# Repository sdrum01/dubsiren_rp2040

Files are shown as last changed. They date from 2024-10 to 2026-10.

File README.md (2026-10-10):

# DUB-IY Dub Siren with RP2040 CPU

DUBSIREN_rp2040 is a project designed to emulate a analog frequency generator for dub and reggae music. The result is the "**DUB-IY**" dub siren. 

Dub sirens are simple synthesizers without VCA (Voltage Controlled Amplifier) or VCF (Voltage Controlled Filter), but usually with a VCO (Voltage Controlled Oscillator) modulated by an LFO (Low Frequency Generator).

Such sirens are typically built with analog circuits. The challenge, however, was to optimize the parameter storage of digital solutions, simplify the electronics and to make it hackable.

**DUB-IY** is based on a Raspberry Pi Pico with an RP2040 CPU. It is fast enough to emulate VCOs and LFOs and offers sufficient options for internal data storage.

The Dub siren creates an square wave signal with an adjustable duty cycle. The sound can be modulated by two LFOs and an envelope generator to modulate the timing parameter. 

Finally, the signal is perfected with an integrated echo effect. 

The following values can be adjusted using potentiometers and switches:

* LFO1 waveform
(square, triple square, triangle, sawtooth, pulse)
* LFO2 waveform (square, triangle, sawtooth)
* Oscillator base frequency
* LFO1 and LFO2 frequency
* LFO1 and LFO2 contribution (negative and positive)
* Timing envelope contribution
* Oscillator waveform duty cycle
* LFO start retriggering
* Delay time (echo)
* Feedback (echo)
* Overall volume

The combination of LFOs 1 and 2 already produces many experimental siren sounds,
but the timing envelope adds significantly more dynamics to the sound.

>[!NOTE]
   >
   >This is a non-profit project with no goal of making big money.
   >It's purely for fun, and we assume no liability!
   
## Waiting List

To reserve one device or PCB pls write me an email: dub-iy@sdrum.elementfx.com

## Documentation

Have a look into the short introduction on YouTube:

- [DUB-IY Introduction](https://youtu.be/Yc06HZqR8gg?si=ktLNwQYJj4XRiWYL) 

There is also a manual explaining the various functions:

- [English Manual](docs/en/index.md)
- [Kurzanleitung Deutsch](docs/de/index.md)

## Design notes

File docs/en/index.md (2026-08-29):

8# DUB-IY short manual 

14.07.2025
<p align="right"><a href="../de">[German version]</a></p>

The Dub Siren DUB-IY is an electronic sound generator that can be used in Dub and Reggae music. It produces modulated, siren-like sounds or effects that can be layered rhythmically or improvised over a track.

## Overview



**Fire Button 1-4 (F1 - F4):** 

Fire a sound. Fire Buttons 1-4 play the saved or edited sounds. Releasing the buttons stops the sound unless one of the adjacent buttons is pressed.

**Fire button 1-4 + Fire Button next to it**:

Hold sound until Fire Button is pressed again.

**Shift (S3) + Fire Button 1-4:**

Select memory bank: Fire Buttons 1-4 load the sounds of the selected bank from memory. A bank consists of 4 buttons. This allows up to 16 sounds to be stored:

- Bank1: 1 to 4
- Bank2: 5 to 8
- Bank3: 9 to 12
- Bank4: 13 to 16

**Save (S4) + Fire Button 1-4:** 

Save sound: any newly edited sound can be easily saved to a Fire Button using this key combination.
Any previously saved sound in the same location will be overwritten.

**Basic state**

If no key is pressed, the last used Fire Button will flash briefly. This shows which sound is currently selected and being edited. This is very helpful before saving to avoid accidentally overwriting a sound.

## Sound Edit 

The sound parameters can be influenced by the following potentiometers (knobs):

**Tune (P1):** Pitch of tone

**Speed (P2):** Speed of the selected LFO

**Mod (P3):** Modulation strength of the selected LFO

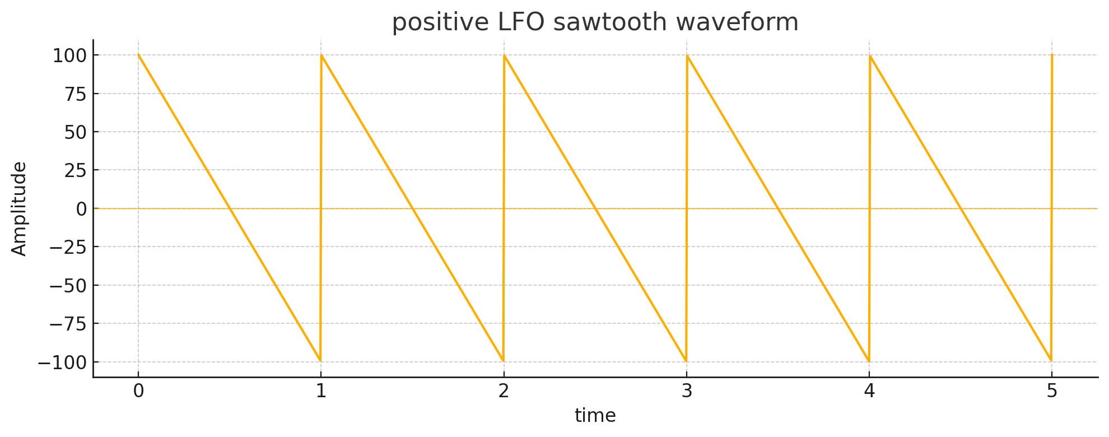
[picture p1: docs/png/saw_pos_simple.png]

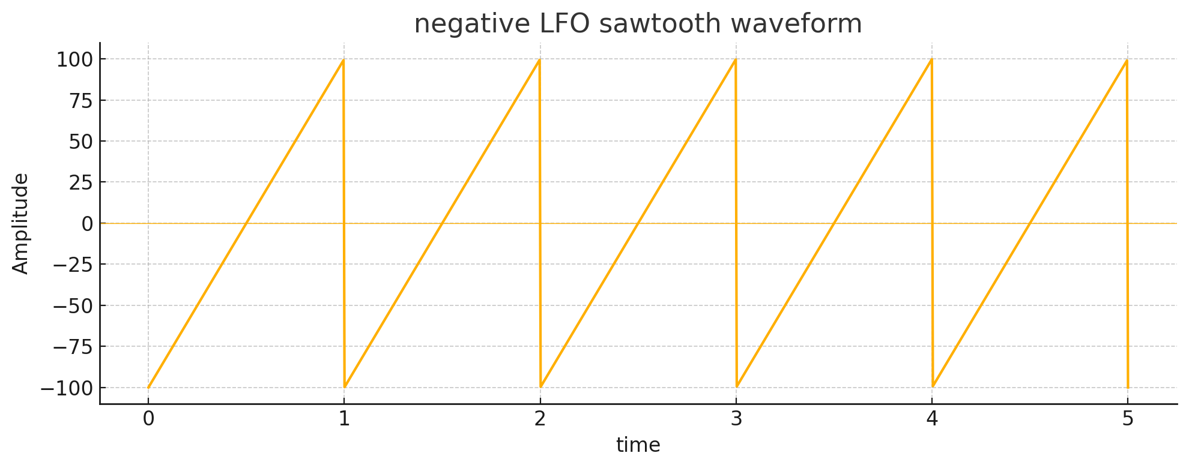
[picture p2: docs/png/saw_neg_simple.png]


_Example of the positive and negative modulation strength of the LFO on a sawtooth wave_

## Sound Edit "Shift Mode" (Shift LED on -> S3)

**Shift Button (S3)**: Switching from normal Sound Edit mode to Sound Edit "Shift Mode."

In "Shift Mode," the potentiometers (knobs) P1, P2, and P3 acquire new functions:

**Tune (P1):** affects the duty cycle (pulse width) of the tone. By default, the pulse width of the tone is 50%, which can be made "thinner."

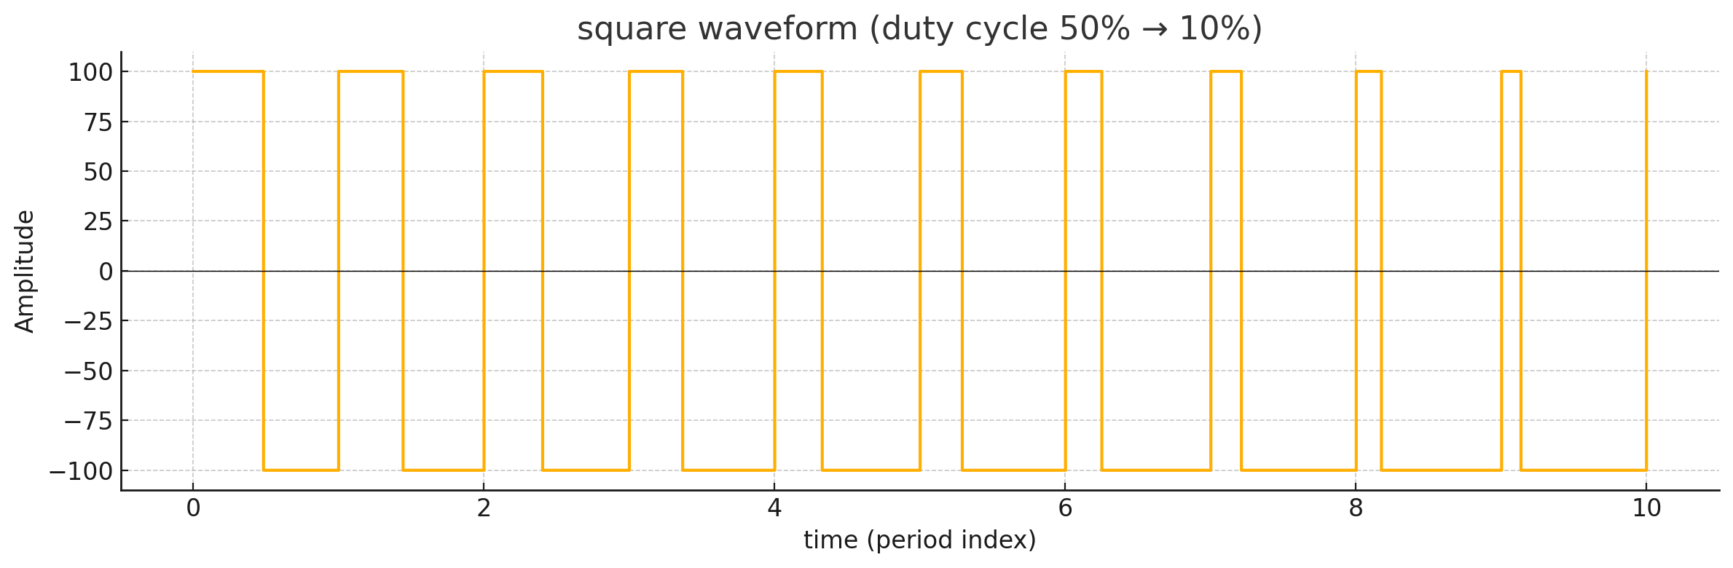
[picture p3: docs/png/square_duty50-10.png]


_Square wave of the tone with pulse width 50% to 10%_

**Speed (P2):** Influences the speed of the LFO with an envelope generator.
This allows the LFO's speed to be changed dynamically.

**Mod (P3):** Influences the modulation strength of the envelope generator:
- Negative value: slow -> fast
- Positive value: fast -> slow

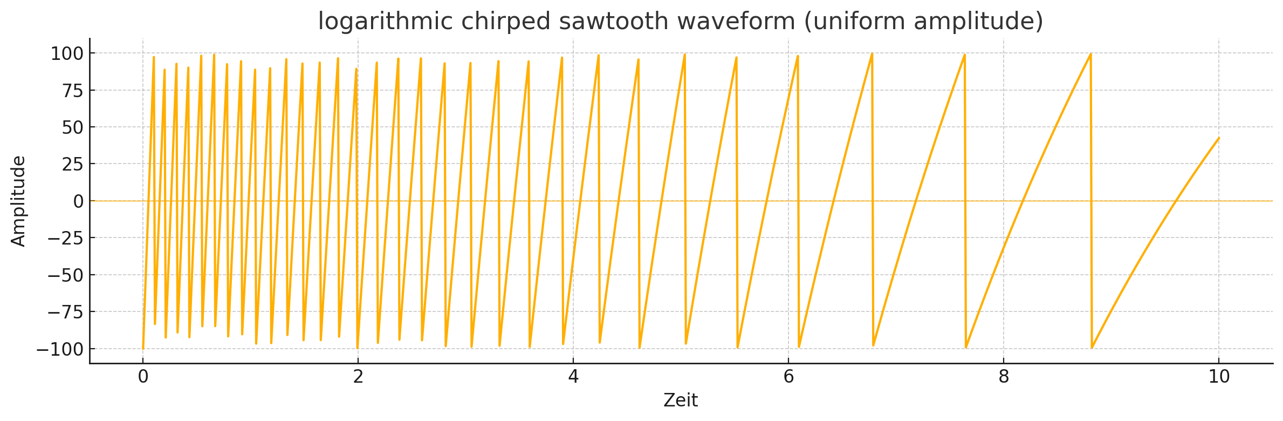
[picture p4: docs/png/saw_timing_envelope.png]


_Example of influencing a sawtooth LFO by the timing envelope generator_.

> [!TIP]
> The timing generator (P2) influences the speed of the active LFO (see [Function Buttons](#function-buttons)).

## Function Buttons

The DUB-YI features two LFOs (low-frequency oscillators) that generate the waveforms used to modulate the sound.

**Wave Button (S1):** 

Selecting the waveform for the selected LFO:

For each LFO, 3 waveforms are selectable
- Rectangle 
- Triangle 
- Sawtooth 
  
The strength and type of the waveform are influenced positively or negatively by the modulation strength (P3), depending on the selected value. At the center position of P3 (0), the respective LFO no longer has any influence.
 
The P3 control has a special feature for LFO1 with the selected waveform "square":
- Positive value: 2 pitches 
- Negative value Wert: 3 pitches 
- Minimal value: interrupted sound 

**LFO Button (S2):** 

Select LFO1 or LFO2.

Each LFO has an independent, storable set of parameters that can be adjusted via P1, P2, and P3.

Both LFOs influence (modulate) each other.

## Examples of Modulation

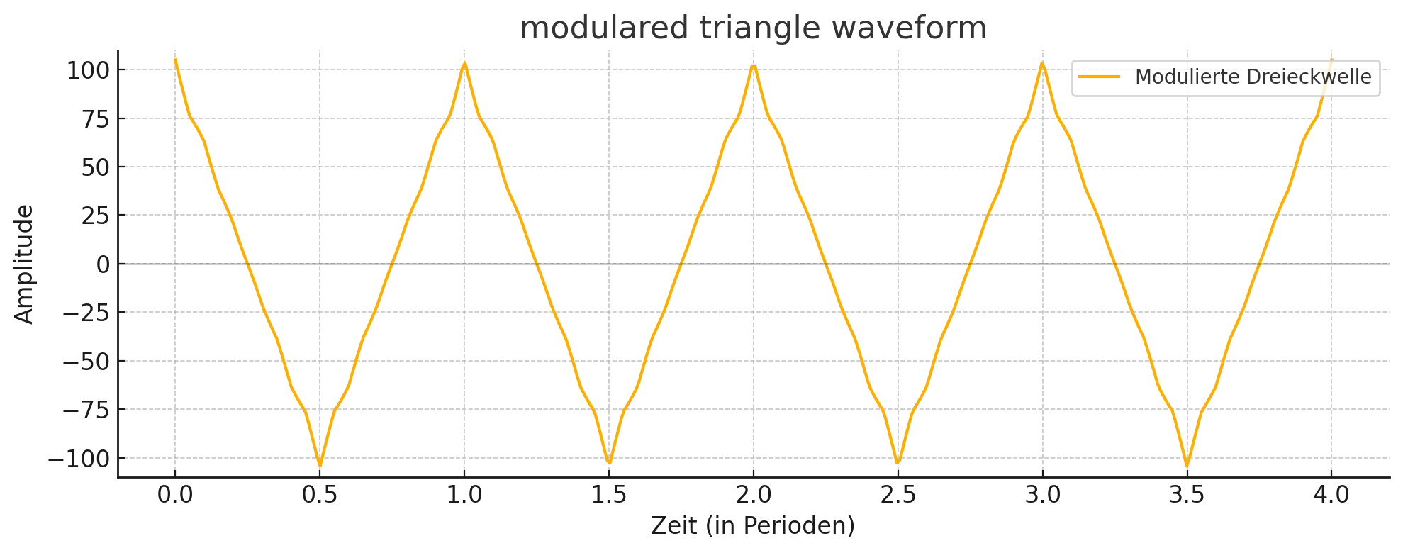
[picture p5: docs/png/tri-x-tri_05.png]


_Modulating a triangle wave from LFO1 with a faster triangle wave from LFO2 at 5%. This creates a slight "vibrato effect"_.

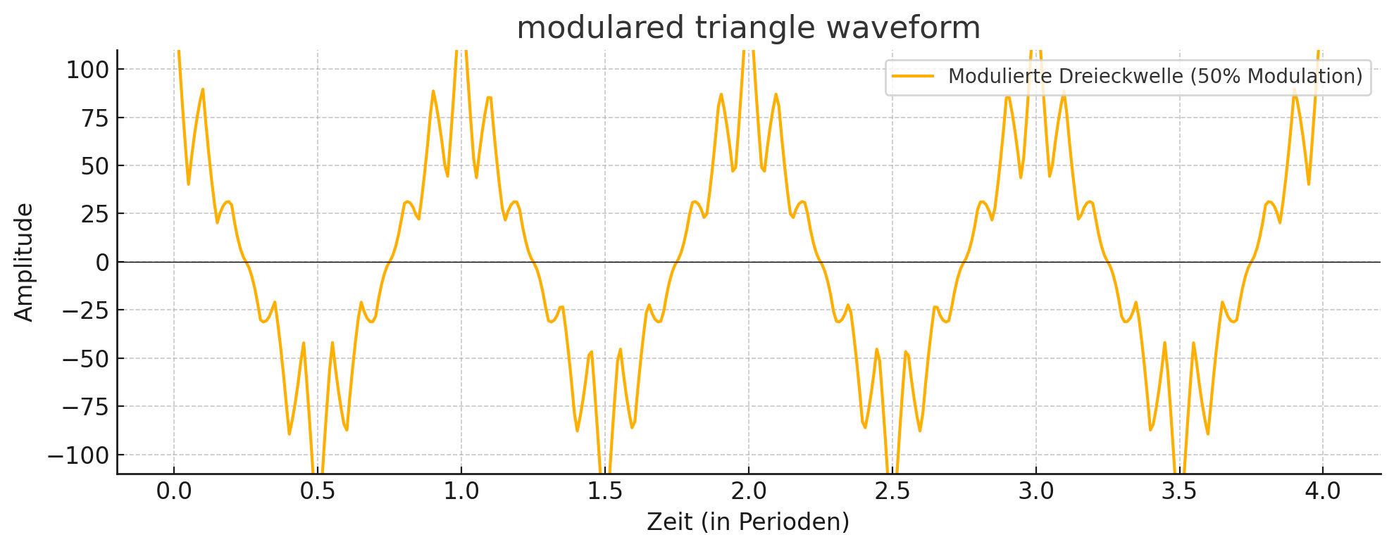
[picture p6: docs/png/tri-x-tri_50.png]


_Modulation of a triangle wave from LFO1 with the triangle wave from LFO2, but with +50% modulation strength_.

## Special Functions / Flags

> [!CAUTION]
> Experimental functions

**LFO Button (S2) pressed + Fire Button 1-4:** 

Various special functions can be switched on using 4 flags.

**Fire1 = Flag1**: LFO2 always starts when a new sound is fired.

**Fire2 = Flag2**: One Shot: after LFO1 has played a full period, the sound stops.

**Fire3 = Flag3**: Modulation multiplier x 2

**Fire4 = Flag4**: Unused

Flag 1 is set by default for new sounds so that LFO1 and LFO2 always start together when the Fire Buttons are pressed. If Flag 1 is turned off, LFO2 continues to run and starts randomly somewhere after the Fire Button is pressed.

## Panic Function (Reset LFO2 and Timing Envelope)

If the sound has become too complex and you just want to hear the basic sound again, you can simply turn off LFO2 and the Timing Envelope by pressing buttons S3 and S4 simultaneously.

## Echo / Delay Effect / Master Volume

**Delay (E1)**: Delay time of the echo, from short to long

**Feedback (E2)**: Strength with which the echo is mixed with the output signal and strength of the feedback of the input signal. At maximum value, the feedback is infinitely long.

**Vol (E3)**: Master Output Volume

> [!Important]
> Echo and master volume (parameters E1 to E3) cannot be saved!

---

> [!Note]
> We reserve the right to improve or adapt the functionality as needed.

Contact dub-iy (at) sdrum.elementfx.com

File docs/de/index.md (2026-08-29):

# DUB-IY Kurzanleitung 

14.07.2025
<p align="right"><a href="../en">[Englische Version]</a></p>

Die Dubsirene DUB-IY ist ein elektronisches Soundgenerator, das in der Dub- und Reggae-Musik eingesetzt werden kann. Sie erzeugt modulierte, sirenenartige Töne oder Effekte, die rhythmisch oder improvisiert über einen Track gelegt werden kann.

## Übersicht



**Firebutton 1-4 (F1 - F4):** 

Sound abfeuern. Mit den Firebuttons 1-4 werden die abgespeicherten oder editierten Sounds abgespielt. Beim Loslassen der Buttons stoppt der Sound, es sei denn, eine der Nachbartasten wurde gedrückt.

**Firebutton 1-4 + benachbarter Firebutton**:

Sound halten bis Firebutton erneut gedrückt wurde.

**Shift (S3) + Firebutton 1-4:**

Speicherbank wählen: Mit den Firebuttons 1-4 werden die Sounds der gewählten Bank aus dem Speicher geladen. Eine Bank besteht aus jeweils vier Buttons. Damit können bis zu 16 Sounds gespeichert werden:

- Bank1: 1 bis 4
- Bank2: 5 bis 8
- Bank3: 9 bis 12
- Bank4: 13 bis 16

**Save (S4) + Firebutton 1-4:** 

Sound abspeichern: Jeder neue editierte Sound kann einfach auf einen Firebutton mit dieser Tastenkombination gespeichert werden. 
Ein eventuell zuvor gespeicherter Sound auf dem selben Speicherplatz wird dabei überschrieben.

**Grundzustand**

Wenn keine Taste gedrückt wurde, blinkt der zuletzt benutzte Firebutton immer wieder kurz. Dadurch ist ersichtlich, welcher Sound gerade gewählt und editiert wird. Dies ist sehr hilfreich vor dem Speichern, um nicht versehentlich einen Sound zu überschreiben.

## Sound Edit 

Die Parameter der Sounds können durch folgende Potentiometer (Drehregler)
beeinflusst werden:

**Tune (P1):** Tonhöhe (Pitch) des Tons

**Speed (P2):** Geschwindigkeit des gewählten LFO

**Mod (P3):** Modulationsstärke des gewählten LFO




_Beispiel der positiven und negativen Modulationsstärke des LFO bei einer Sägezahnwelle_

## Sound Edit "Shift Mode" (Shift LED an -> S3)

**Shift-Button (S3)**: Umschalten vom normalen Sound-Edit mode in den Sound Edit "Shift Mode".

Im "Shift Mode" bekommen die Potentiometer (Drehregler) P1, P2, P3 neue Funktionen:

**Tune (P1):** beeinflusst das Duty Cycle (Pulsbreite) des Tons. Standardmäßig ist die Pulsbreite des Tons 50%, und kann dadurch "dünner" gemacht werden.



_Rechtecksignal des Tons mit Pulsbreite 50% bis 10%_

**Speed (P2):** beeinflusst die Geschwindigkeit des LFO mit einem Envelop-Generator (Hüllkurven-Generator)
Dadurch kann der LFO dynamisch in seiner Geschwindigkeit geändert werden 

**Mod (P3):** beeinflusst die Modulationsstärke des Envelop-Generator:
- negativer Wert: langsam -> schnell 
- positiver Wert: schnell -> langsam



_Beispiel einer Beeinflussung eines Sägezahhn-LFO durch den Timing-Envelope-Generator_.

> [!TIP]
> Der Timing-Generator (P2) beeinflusst die Geschwindigkeit des aktiven LFO (siehe [Funktionsbuttons](#funktionsbuttons)).

## Funktionsbuttons

Das DUB-YI verfügt über zwei LFO (Low-Frequency Oscillator), welche
die Wellenformen erzeugen, mit dem der Ton moduliert wird.

**Wave-Button (S1):** 

Selektieren der Wellenform für den gewählten LFO:

Bei jedem LFO sind grundsätzlich 3 Wellenformen selektierbar
- Rechteck 
- Dreieck 
- Sägezahn 
  
Die Stärke und zum Teil die Art der Wellenform wird durch die Modulationsstärke (P3) positiv / negativ in Abhängigkeit des gewählten Wertes beeinflusst. Bei der Mittelstellung von P3 (0) hat der jeweilige LFO keinen Einfluss mehr.
 
Beim LFO1 hat der Regler P3 mit gewählter Wellenform "Rechteck" eine Besonderheit:
- positiver Wert: 2 Töne 
- negativer Wert: 3 Töne 
- Minimaler Wert: Unterbrochener Ton 

**LFO-Button (S2):** 

Selektieren von LFO1 oder LFO2.

Jeder LFO hat einen unabhängigen, abspeicherbaren Parametersatz, der über P1, P2, P3 eingestellt werden kann. 
Beide LFO beeinflussen (modulieren) sich gegenseitig.

## Beispiele der Modulation



_Modulation einer Dreieckwelle von LFO1 mit einer schnelleren Dreieckwelle LFO2 mit 5%_. _Es entsteht ein leichter "Vibrato-Effekt"_.



_Modulation einer Dreieckwelle von LFO1 mit der Dreieckwelle LFO2, aber mit +50% Modulationsstärke_.

## Spezialfunktionen / Flags

> [!CAUTION]
> Experimentelle Funktion

**LFO-Button (S2) gedrückt + Firebutton 1-4:** 

Über 4 Flags verschiedene Sonderfunktionen eingeschaltet werden.

**Fire1 = Flag1**: LFO2 startet immer bei neu beim abfeuern von Sounds.

**Fire2 = Flag2**: One Shot: nach dem LFO1 eine vollständige Periode gespielt hat, wird der Sound gestoppt

**Fire3 = Flag3**: Multiplikator der Modulation x 2

**Fire4 = Flag4**: Unbenutzt

Flag 1 ist standardmäßig bei neuen Sounds gesetzt, damit LFO1 und LFO2 beim Drücken der Firebuttons immer zusammen gestartet werden. Wenn Flag 1 ausgeschaltet wird, läuft der LFO2 weiter und startet nach dem drücken des Firebutton irgendwo zufällig.

## Panik-Funktion (Reset LFO2 und Timing-Envelope)

Sollte der Sound zu komplex geworden sein, und man möchte nur wieder den Grundsound hören, kann man den LFO2 und den Timing-Envelope einfach ausschalten, indem man die Taster S3 + S4 gleichzeitig drückt.

## Echo / Delayeffekt / Mastervolume

**Delay (E1)**: Verzögerungszeit des Echo, von kurz nach lang

**Feedback (E2)**: Stärke, mit der das Echo dem Ausgangssignal zugemischt wird und Stärke der Rückkopplung (Feedback) des Eingangssignals. Bei maximalem Wert ist das Feedback unendlich lang.

**Vol (E3)**: Ausgangslautstärke Master

> [!Important]
> Echo und Mastervolume (Parameter E1 bis E3) sind nicht abspeicherbar! 

---

> [!Note]
> Wir behalten uns vor, die Funktionalität bei Bedarf zu verbessern oder anzupassen. 

Kontakt
dub-iy (at) sdrum.elementfx.com

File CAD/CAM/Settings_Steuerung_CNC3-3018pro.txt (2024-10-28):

Version=11244
Setting type=CNC controller settings

;----------------------------------------------------------------------------------------------------------------------------------------------------
;Vor Änderungen an dieser Datei muss Estlcam unbedingt geschlossen werden - sonst gehen die Änderungen verloren!
;Die "Steuerungselektronik" Liste der Grundeinstellungen setzt alles auf Standardwerte zurück - klicke Sie nach manuellen Änderungen nicht mehr an!
;----------------------------------------------------------------------------------------------------------------------------------------------------

Enabled=yes
Hardware=G_Safe
Firmware=G_Safe
Last Upload=11244
Port=COM19

;Axis configuration
Steps rev X=3200
Steps rev Y=3200
Steps rev Z=3200
Distance rev X=4
Distance rev Y=4
Distance rev Z=4
Fmax X=20
Fmax Y=20
Fmax Z=20
Inertia X=85
Inertia Y=85
Inertia Z=85
Inverted X=no
Inverted Y=yes
Inverted Z=no
Current X=0,5
Current Y=0,5
Current Z=0,5

Acceleration distance=2
Min feedrate=1
Fast Diagonal=no
Invert enable output=no
Invert step signal=no
Switch enable output=no

Override oversampling=-1
Override pulse=-2147483648
Pulse pause=0
Manual programming reset=no

Position X=41238
Position Y=0
Position Z=800000
Home offset X=0
Home offset Y=0
Home offset Z=0
Feedrate=10
RPM=24000
Last CNC file=G:\Produktion\AV\Automation\SSA\RnD\Software\tools\CAM\estlcam\test\Zeichnung.nc
Last CNC line=0
Last CNC rotation=0
Balance message=yes

;Spindle configuration
RPM min=8000
RPM max=24000
RPM delay=1
PWM min=0
PWM max=100
PWM Frequency=0
Spindle output inverted=no

;Inputs
Input 1 name=Eingang 1
Input 1 function=0
Input 1 inverted=no
Input 1 pull-up=yes

Input 2 name=Eingang 2
Input 2 function=0
Input 2 inverted=no
Input 2 pull-up=yes

Input 3 name=Eingang 3
Input 3 function=0
Input 3 inverted=no
Input 3 pull-up=yes

Input 4 name=Eingang 4
Input 4 function=0
Input 4 inverted=no
Input 4 pull-up=yes

Input 5 name=Eingang 5
Input 5 function=0
Input 5 inverted=no
Input 5 pull-up=yes

Input 6 name=Eingang 6
Input 6 function=0
Input 6 inverted=no
Input 6 pull-up=yes

Input 7 name=Eingang 7
Input 7 function=0
Input 7 inverted=no
Input 7 pull-up=yes

Input 8 name=Eingang 8
Input 8 function=0
Input 8 inverted=no
Input 8 pull-up=yes

Input 9 name=Eingang 9
Input 9 function=0
Input 9 inverted=no
Input 9 pull-up=yes

Input 10 name=Eingang 10
Input 10 function=0
Input 10 inverted=no
Input 10 pull-up=yes

Input 11 name=Eingang 11
Input 11 function=0
Input 11 inverted=no
Input 11 pull-up=yes

Input 12 name=Eingang 12
Input 12 function=0
Input 12 inverted=no
Input 12 pull-up=yes

Input 13 name=Eingang 13
Input 13 function=0
Input 13 inverted=no
Input 13 pull-up=yes

Input 14 name=Eingang 14
Input 14 function=0
Input 14 inverted=no
Input 14 pull-up=yes

Input 15 name=Eingang 15
Input 15 function=0
Input 15 inverted=no
Input 15 pull-up=yes

Input 16 name=Eingang 16
Input 16 function=0
Input 16 inverted=no
Input 16 pull-up=yes

;Outputs
Output 1 name=Ausgang 1
Output 1 picture=img_flood

Output 2 name=Ausgang 2
Output 2 picture=img_mist

Output 3 name=Ausgang 3
Output 3 picture=img_vac

Output 4 name=Ausgang 4
Output 4 picture=img_compressor

Output 5 name=Ausgang 5
Output 5 picture=img_light

Output 6 name=Ausgang 6
Output 6 picture=

Output 7 name=Ausgang 7
Output 7 picture=

Output 8 name=Ausgang 8
Output 8 picture=

;Homing
Auto home=no
Home switch location X=0
Home switch location Y=0
Home switch location Z=1
Homing speed=20
Homing probe speed=1
Homing switch precise=no
Homing back up distance=5
Check step losses=yes
Zero after homing=no
Travel limits enabled=no
Travel limit X=1000
Travel limit Y=1000
Travel limit Z=1000
Deceleration distance=25
Park after homing=no
Park after controller start=no
Park after CNC program end=no
Park after M00 M01=no
Parking position X=0
Parking position Y=0
Parking position Z=0
Homing Safety Msg=no

;Tool sensor
Tool sensor probe speed=0,10000000000000001
Tool sensor back up distance=1
Tool sensor fixed position=no
Tool sensor fixed position X=0
Tool sensor fixed position Y=0
Tool sensor fixed position Z=0
Tool sensor fixed Z=no
Tool sensor Z value=0

;Touch plate
Touch plate probe speed=5
Touch plate probe distance=20
Touch plate angle measurement distance=50
Touch plate margin X=5
Touch plate margin Y=5
Touch plate margin Z=5

;Keyboard
Keyboard enabled=yes
Key 0=104
Key 1=105
Key 2=102
Key 3=99
Key 4=98
Key 5=97
Key 6=100
Key 7=103
Key 8=33
Key 9=34
Key 10=38
Key 11=40
Key 12=39
Key 13=37
Key 14=113
Key 15=32
Key 16=50
Key 17=51
Key 18=52
Key 19=53
Key speed 0=2
Key speed 1=10
Key speed 2=25
Key speed 3=50
Key speed 4=100

;Gamepad
Gamepad enabled=no
Gamepad low speed=2
Gamepad high speed=100
Gamepad exponent=60
Gamepad sensitivity=2
Gamepad single axis=no
Gamepad beep=no

;External controls
Feed override knob enabled=no
Feed override knob min pos=13107
Feed override knob max pos=52429
Spindle override knob enabled=no
Spindle override knob min pos=13107
Spindle override knob max pos=52429
Jog wheel enabled=no
Jog wheel X inverted=no
Jog wheel Y inverted=no
Jog wheel Z inverted=no
Jog wheel coupled 1=yes
Jog wheel coupling factor 1=1:1
Jog wheel speed 1=10
Jog wheel coupled 2=yes
Jog wheel coupling factor 2=2:1
Jog wheel speed 2=50
Jog wheel coupled 3=yes
Jog wheel coupling factor 3=1:1
Jog wheel speed 3=100
Jog wheel coupled 4=no
Jog wheel coupling factor 4=1:1
Jog wheel speed 4=10
Jog wheel coupled 5=no
Jog wheel coupling factor 5=1:1
Jog wheel speed 5=50
Jog wheel coupled 6=no
Jog wheel coupling factor 6=1:1
Jog wheel speed 6=100
Jog wheel sensitivity=75
Joystick X enabled=no
Joystick Y enabled=no
Joystick Z enabled=no
Joystick X inverted=no
Joystick Y inverted=no
Joystick Z inverted=no
Joystick X center=50
Joystick Y center=50
Joystick Z center=50
Joystick X backlash=10
Joystick Y backlash=10
Joystick Z backlash=10
Joystick speed 1=100
Joystick speed 2=10
Joystick speed 3=20
Joystick speed 4=100
Joystick speed 5=100
Joystick speed 6=100
Joystick expo 1=60
Joystick expo 2=0
Joystick expo 3=0
Joystick expo 4=0
Joystick expo 5=0
Joystick expo 6=0
Joystick single axis 1=no
Joystick single axis 2=yes
Joystick single axis 3=yes
Joystick single axis 4=no
Joystick single axis 5=no
Joystick single axis 6=no
Joystick beep 1=yes
Joystick beep 2=yes
Joystick beep 3=yes
Joystick beep 4=no
Joystick beep 5=no
Joystick beep 6=no
Joystick sensitivity=70
Module=

Webcam application=
Webcam window margin left=0
Webcam window margin right=0
Webcam window margin top=0
Webcam window margin bottom=0
Webcam tool offset X=0
Webcam tool offset Y=0
Webcam tool offset Z=0
Webcam aligned to preview=no

Makro Name 1=
Makro 1=
Makro Name 2=
Makro 2=
Makro Name 3=
Makro 3=
Makro Name 4=
Makro 4=
Makro Name 5=
Makro 5=

;Misc
Back up distance=1
Surface scan speed=2
Touch mode=no

;Bootloader
Bootloader Baudrate=57600
Bootloader Reset_Time=20
Bootloader Wait_Time=500

Preset info=

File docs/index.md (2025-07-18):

# DUB-IY Kurzanleitung 

<p align="center"><a href="en/">[Englische Version]</a></p>
<p align="center"><a href="de/">[Deutsche Version]</a></p>



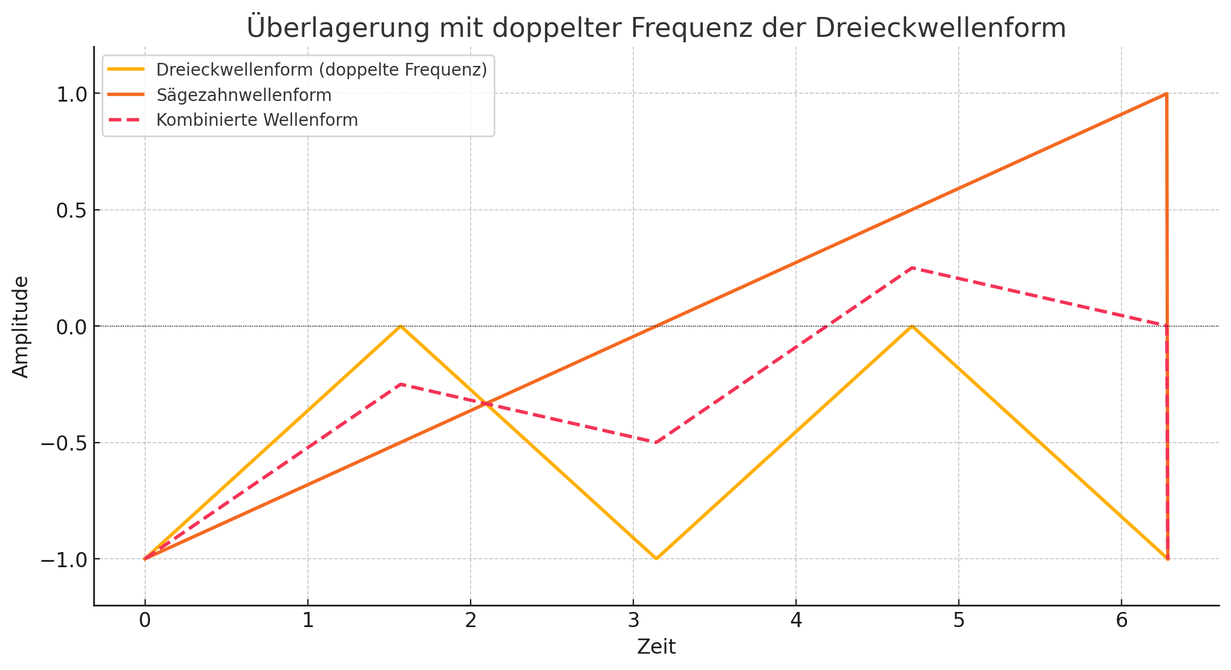
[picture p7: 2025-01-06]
docs/png/saw-x-tri_50.png

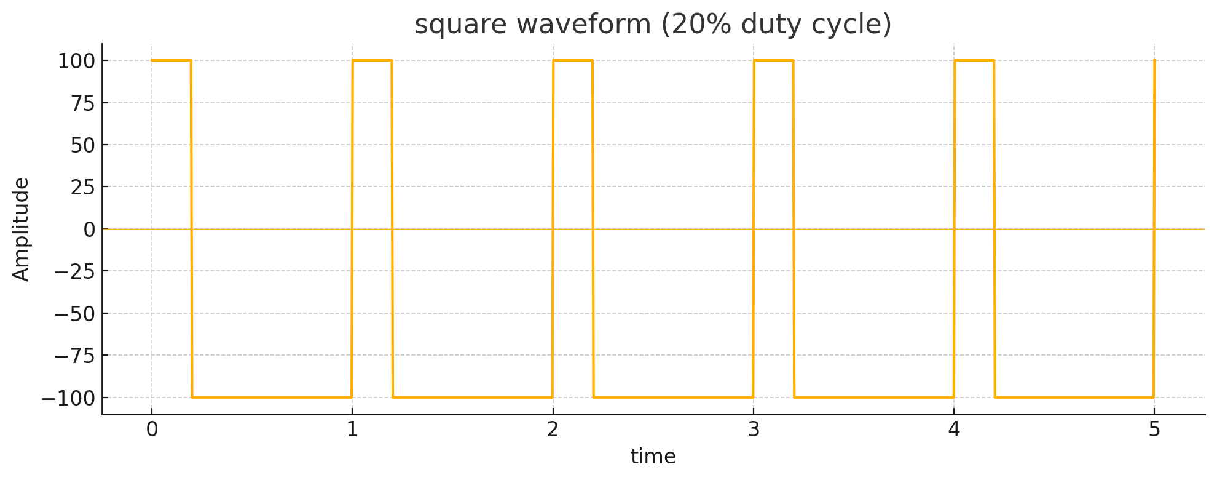
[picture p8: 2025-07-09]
docs/png/square_duty20.png

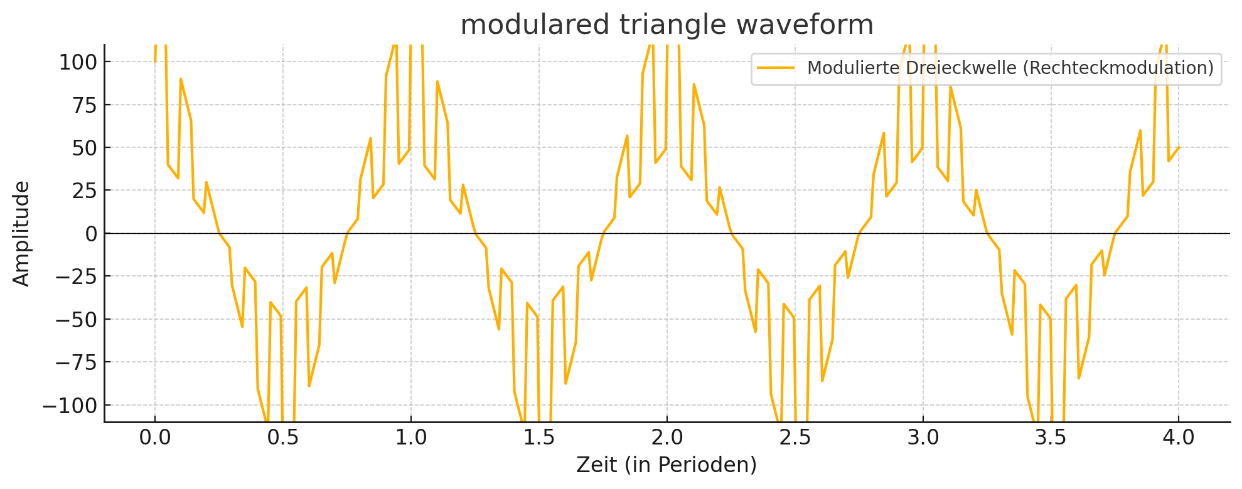
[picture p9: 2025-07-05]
docs/png/tri-x-rect_50.png

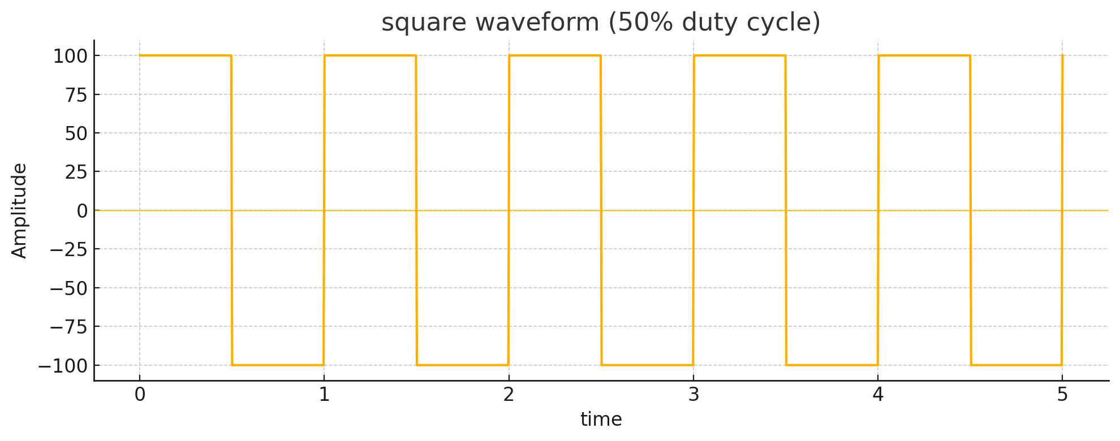
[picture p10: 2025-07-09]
docs/png/square_duty50.png

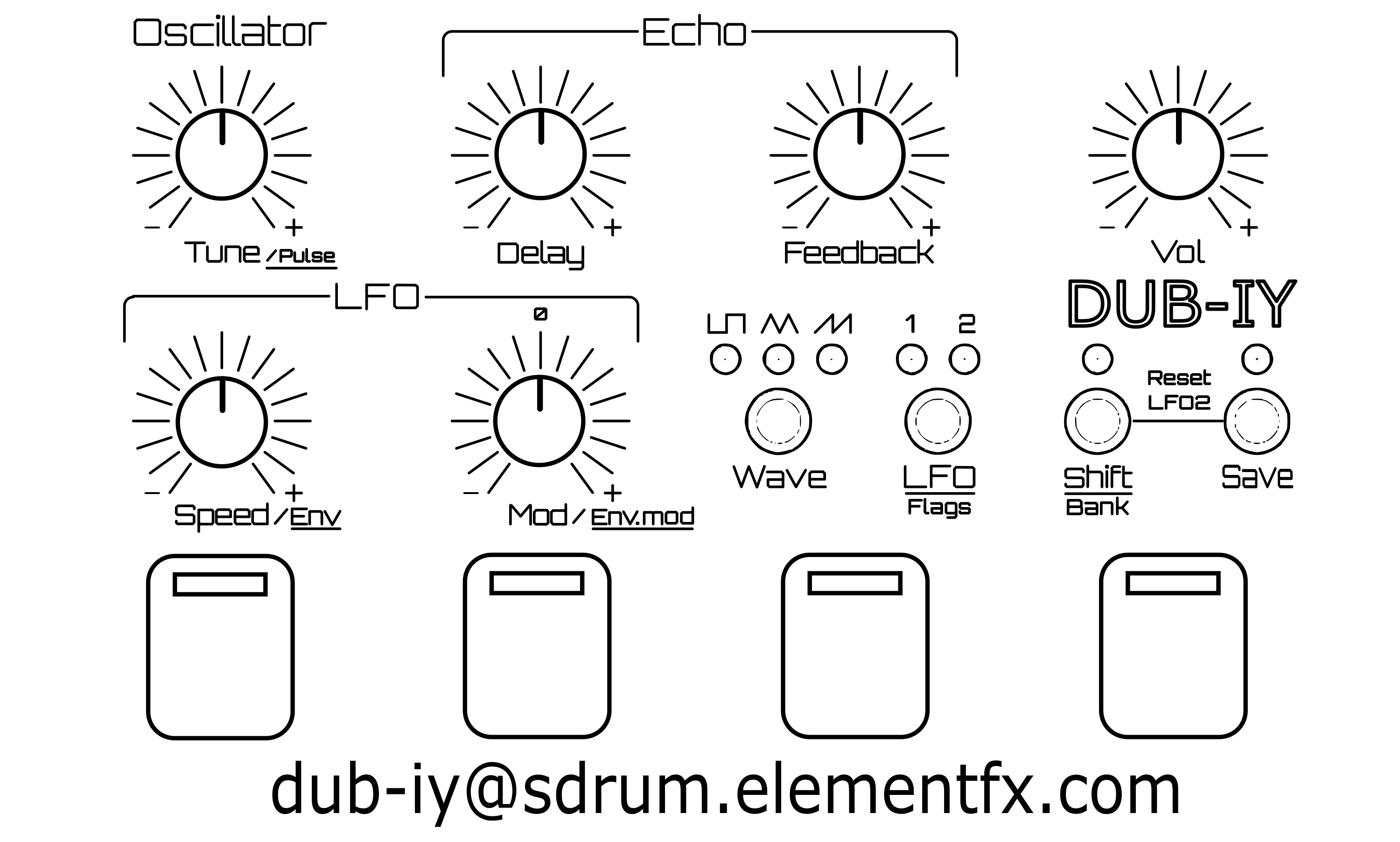
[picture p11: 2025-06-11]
CAD/DXF/Front_DUBIY_mit_Beschriftung_buisnesscard_v3.png

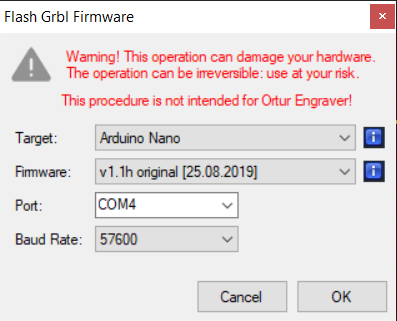
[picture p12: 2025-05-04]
CAD/CAM/LaserGRBL/flash_firmware.png

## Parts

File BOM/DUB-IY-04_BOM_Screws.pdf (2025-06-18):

Reference | Name | Qty Bemerkung | Hersteller Partno. | Conrad Orderno. RS Online
| 1 Gewindestift M2 x 4mm | 6 für Potiknopf | Toolcraft TO-5370165 | 1790055 - NA431-965
2 Zylinderkopf Innensechskantschraube, Stahl schwarz passiviert, M1.6 x 0.35mm, 6mm 5 für Leiste | 304-17-406
| 3 Zylinderkopf Innensechskantschraube, Edelstahl A2 , M3 x 0.5mm, 6mm | 7 Befestigung PCB | | 303-95-067
| 4 Senkkopf Innensechskantschraube, Edelstahl DIN 7991 A4, M3 x 0.5mm, 8mm | 4 Gehäuseschraube | | 304-17-413

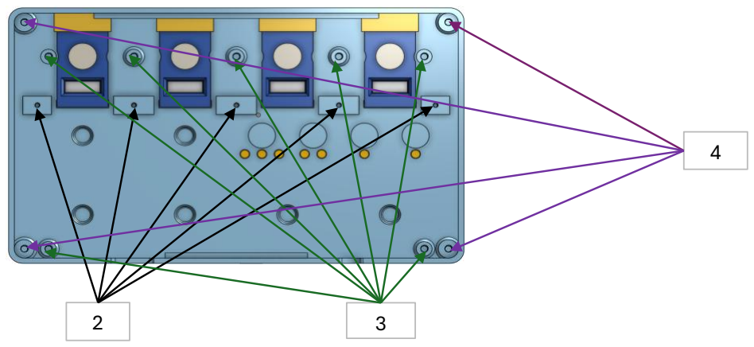
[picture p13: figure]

1

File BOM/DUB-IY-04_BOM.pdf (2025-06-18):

Reference | Value | Datasheet Footprint | Qty
A1 | RaspberryPi-Pico | https://datasheets.raspberrypi.com/pico/pico-datasheet.pdf MCU_RaspberryPi_and_Boards:RPi_Pico_SMD_TH 1
C1,C8 | 100µ | ~ | Capacitor_SMD:CP_Elec_6.3x5.8 | 2
C2,C3,C4,C5,C6,C7,C10,C14,C15 | 100n | ~ | -- verschiedene Werte -- | 9
C9 | 47µ | ~ | Capacitor_SMD:CP_Elec_6.3x5.3 | 1
C11,C20 | 560pF | ~ | Capacitor_SMD:C_0805_2012Metric_Pad1.18x1.45mm_HandSolder 2
C12 | 3,9nF | ~ | Capacitor_SMD:C_0805_2012Metric_Pad1.18x1.45mm_HandSolder 1
C13 | 68nF | ~ | Capacitor_SMD:C_0805_2012Metric_Pad1.18x1.45mm_HandSolder 1
C16 | 3,3nF | ~ | Capacitor_SMD:C_0805_2012Metric_Pad1.18x1.45mm_HandSolder 1
C17,C18 | 4,7µ | ~ | Capacitor_Tantalum_SMD:CP_EIA-2012-12_Kemet-R_Pad1.30x1.05mm_HandSolder 2
C19 | 10n | ~ | Capacitor_SMD:C_0805_2012Metric_Pad1.18x1.45mm_HandSolder 1
C21,C23 | 10µ | ~ | Capacitor_SMD:CP_Elec_4x5.7 | 2
C22 | 82nF | ~ | Capacitor_SMD:C_0805_2012Metric_Pad1.18x1.45mm_HandSolder 1
C24 | 220n | ~ | Capacitor_SMD:C_1206_3216Metric 1
D1 | LED LFO2 | ~ | LED_THT:LED_D3.0mm | 1
D2 | LED LFO1 | ~ | LED_THT:LED_D3.0mm | 1
D3 | LED Shift1 | ~ | LED_THT:LED_D3.0mm | 1
D4 | LED Fire1 | ~ | LED_THT:LED_D3.0mm | 1
D5 | LED Fire2 | ~ | LED_THT:LED_D3.0mm | 1
D6 | LED Fire3 | ~ | LED_THT:LED_D3.0mm | 1
D7 | LED Fire4 | ~ | LED_THT:LED_D3.0mm | 1
D8 | LED_WF_Squ | ~ | LED_THT:LED_D3.0mm | 1
D9 | LED Shift2 | ~ | LED_THT:LED_D3.0mm | 1
D10 | LED_WF_Tri | ~ | LED_THT:LED_D3.0mm | 1
D11 | LED_WF_Saw | ~ | LED_THT:LED_D3.0mm | 1
D20 | SK110 | ~ | Diode_SMD:D_SMA-SMB_Universal_Handsoldering 1
J1 | AudioJack3_Ground ~ | Audiosockets:Jack_3.5mm_Ledino_KB3SPRS_Horizontal 1
J2 | Power Jack | ~ | Connector_BarrelJack:BarrelJack_GCT_DCJ200-10-A_Horizontal 1
R2,R3,R7,R8,R9,R10,R11,R12,R16,R17,R18 | 680 ~ | Resistor_SMD:R_1206_3216Metric 11
R4,R5,R6 | 1k | ~ | Resistor_SMD:R_1206_3216Metric | 3
R19,R27 | 4,7k | ~ | Resistor_SMD:R_1206_3216Metric | 2
R20,R21,R26,R28,R29,R30,RV1,RV2,RV3 | 10k | ~ | -- verschiedene Werte -- | 9
R22,R25 | 15k | ~ | Resistor_SMD:R_1206_3216Metric | 2
R23,RV4,RV5 | 100k | ~ | -- verschiedene Werte -- | 3
R24 | 5,6k | ~ | Resistor_SMD:R_1206_3216Metric | 1
RV6 | 50k | ~ | poti_alps:Potentiometer_Alps_RK09K_Single_Vertical 1
SW1 | LFO1/2 | ~ | Button_Switch_THT:SW_PUSH_6mm1
SW2 | Select LFO WaveForm~ | Button_Switch_THT:SW_PUSH_6mm1
SW3 | Fire4 | ~ | Button_Switch_THT:SW_PUSH_6mm1
SW4 | Fire3 | ~ | Button_Switch_THT:SW_PUSH_6mm1
SW5 | Fire2 | ~ | Button_Switch_THT:SW_PUSH_6mm1
SW6 | Fire1 | ~ | Button_Switch_THT:SW_PUSH_6mm1
SW7 | Shift2/Save | ~ | Button_Switch_THT:SW_PUSH_6mm1
SW8 | Shift1 / Select Bank | ~ | Button_Switch_THT:SW_PUSH_6mm1
U2 | PT2399 | Package_DIP:DIP-16_W7.62mm_Socket_LongPads 1
U3 | L7805 | http://www.st.com/content/ccc/resource/technical/document/datasheet/41/4f/b3/b0/12/d4/47/88/CD00000444.pdf/files/CD00000444.pdf/jcr:content/translations/en.CD0000044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 Package_TO_SOT_SMD:TO-252-3_TabPin2 1
Netzteil 12V 0,5A | | | | 1
PCB | | | | 1
Adapter Klinke 3,5mm-6,3mm | | | | 10

DNP Reichelt | EK | EK Summe
RASP PI PICO H | 5,46 | 5,46
FT-V 100U 16 | 0,24 | 0,48
0,02 | 0,18
ELN RVS-16V470MU | 0,10 | 0,10
0,02 | 0,04
0,02 | 0,02
0,02 | 0,02
0,02 | 0,02
KEM X5R0805 4,7U | 0,10 | 0,20
0,02 | 0,02
SMD ELKO 10/16 | 0,04 | 0,08
0,02 | 0,02
0,02 | 0,02
3004Y1D-EHC-B (https://www.reichelt.de/de/de/shop/produkt/led_3mm_bedrahtet_gelb_350_mcd_60_-361904) | 0,08 | 0,08 gelb
3004Y1D-EHC-B (https://www.reichelt.de/de/de/shop/produkt/led_3mm_bedrahtet_gelb_350_mcd_60_-361904) | 0,08 | 0,08 gelb
3004Y1D-EHC-B (https://www.reichelt.de/de/de/shop/produkt/led_3mm_bedrahtet_gelb_350_mcd_60_-361904) | 0,08 | 0,08 gelb
3034B2D-EHD-A | 0,08 | 0,08 blau
3034B2D-EHD-A | 0,08 | 0,08 blau
3034B2D-EHD-A | 0,08 | 0,08 blau
3034B2D-EHD-A | 0,08 | 0,08 blau
3004G6D-EHB-S (https://www.reichelt.de/de/de/shop/produkt/led_3mm_bedrahtet_gruen_200_mcd_60_-361906) | 0,08 | 0,08 grün
3004R2D-EPC-S (https://www.reichelt.de/de/de/shop/produkt/led_3mm_bedrahtet_rot_100_mcd_60_-361901) | 0,15 | 0,15 rot
3004G6D-EHB-S (https://www.reichelt.de/de/de/shop/produkt/led_3mm_bedrahtet_gruen_200_mcd_60_-361906) | 0,08 | 0,08 grün
3004G6D-EHB-S (https://www.reichelt.de/de/de/shop/produkt/led_3mm_bedrahtet_gruen_200_mcd_60_-361906) | 0,08 | 0,08 grün
0,02 | 0,02
EBS 35 | 0,36 | 0,36
CLIFF FCR681465 | 1,10 | 1,10
0,02 | 0,22
0,02 | 0,06
0,02 | 0,04
RK09K113-LIN10K | 0,99 | 8,91
0,02 | 0,04
RK09K113-LIN100K | 0,99 | 2,97
0,02 | 0,02
RK09K113-LIN50K | 0,99 | 0,99
OMR B3F-1002 | 0,29 | 0,29
OMR B3F-1002 | 0,29 | 0,29
RAFI 100.502 | 1,15 | 1,15
RAFI 100.502 | 1,15 | 1,15
RAFI 100.502 | 1,15 | 1,15
RAFI 100.502 | 1,15 | 1,15
OMR B3F-1002 | 0,29 | 0,29
OMR B3F-1002 | 0,29 | 0,29
4,00 | 4,00 CHINA
L78M05CDT STM | 0,21 | 0,21
EA1005BHES1201 oder
YS6V-1200500E | 7,00 | 7,00
10,00 | 10,00
2,00 | 20,00

incl. MWST
SUMME | 69,31 | 82,4789

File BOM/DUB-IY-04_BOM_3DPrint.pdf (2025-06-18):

Position Name | STL File | Filament Color | Filament Material QTY
1 | Body | DIYBody_V12.3.stl | Black | PLA | 1
2 | Body bottom | DIYBodyBottomSlim_V12.3.stl | Black | PLA | 1
3 | Functionsbuttons / Shift | DIYKnobShift_V12.2_8mm.stl | White | PLA | 4
4 | Fire Button | DIYKnobFire_V12.3.stl | White | PLA | 4
5 | Fire Button extension | DIYKnobFire - Stößel_V12.3_1.stl | White | PLA | 4
6 | Fire Button Inlay | DIYKnobFire - Inlay_V12.3.stl | White | PLA | 4
7 | stribe for Buttons | DIYBodyStreifen.stl | White or Black or whatever | PLA | 1
8 | Potiknob | PotiKnobV25.stl | Black | PLA | 6
9 | Potiknob Inlay | PotiKnob - Inlays_x10_V12.0.stl | Transparent | PLA | 6

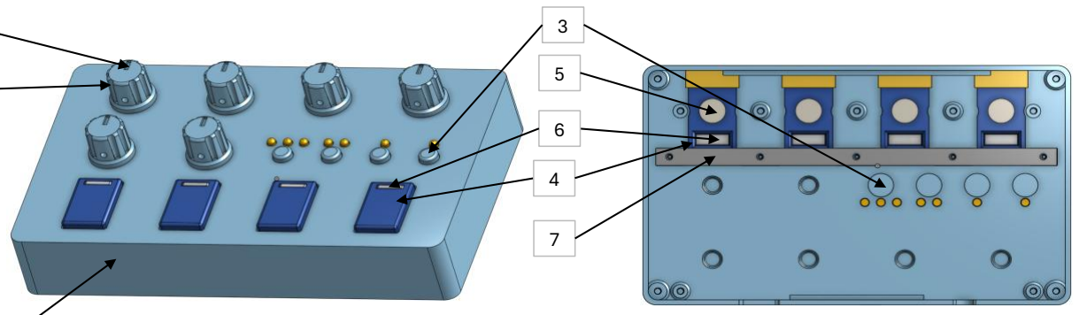
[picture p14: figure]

1 | 2

8

9

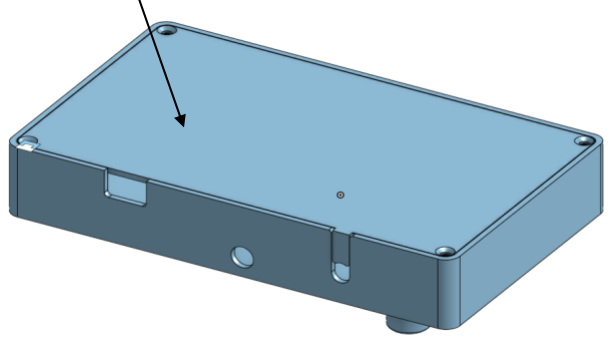
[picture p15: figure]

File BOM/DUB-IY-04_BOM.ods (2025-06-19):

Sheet: electronic
Reference | Value | Datasheet | Footprint | Qty | DNP | Reichelt | EK | EK Summe
A1 | RaspberryPi-Pico | https://datasheets.raspberrypi.com/pico/pico-datasheet.pdf | MCU_RaspberryPi_and_Boards:RPi_Pico_SMD_TH | 1 |  | RASP PI PICO H | 5,46 | 5,46
C1,C8 | 100µ | ~ | Capacitor_SMD:CP_Elec_6.3x5.8 | 2 |  | FT-V 100U 16 | 0,24 | 0,48
C2,C3,C4,C5,C6,C7,C10,C14,C15 | 100n | ~ | -- verschiedene Werte -- | 9 |  |  | 0,02 | 0,18
C9 | 47µ | ~ | Capacitor_SMD:CP_Elec_6.3x5.3 | 1 |  | ELN RVS-16V470MU | 0,10 | 0,10
C11,C20 | 560pF | ~ | Capacitor_SMD:C_0805_2012Metric_Pad1.18x1.45mm_HandSolder | 2 |  |  | 0,02 | 0,04
C12 | 3,9nF | ~ | Capacitor_SMD:C_0805_2012Metric_Pad1.18x1.45mm_HandSolder | 1 |  |  | 0,02 | 0,02
C13 | 68nF | ~ | Capacitor_SMD:C_0805_2012Metric_Pad1.18x1.45mm_HandSolder | 1 |  |  | 0,02 | 0,02
C16 | 3,3nF | ~ | Capacitor_SMD:C_0805_2012Metric_Pad1.18x1.45mm_HandSolder | 1 |  |  | 0,02 | 0,02
C17,C18 | 4,7µ | ~ | Capacitor_Tantalum_SMD:CP_EIA-2012-12_Kemet-R_Pad1.30x1.05mm_HandSolder | 2 |  | KEM X5R0805 4,7U | 0,10 | 0,20
C19 | 10n | ~ | Capacitor_SMD:C_0805_2012Metric_Pad1.18x1.45mm_HandSolder | 1 |  |  | 0,02 | 0,02
C21,C23 | 10µ | ~ | Capacitor_SMD:CP_Elec_4x5.7 | 2 |  | SMD ELKO 10/16 | 0,04 | 0,08
C22 | 82nF | ~ | Capacitor_SMD:C_0805_2012Metric_Pad1.18x1.45mm_HandSolder | 1 |  |  | 0,02 | 0,02
C24 | 220n | ~ | Capacitor_SMD:C_1206_3216Metric | 1 |  |  | 0,02 | 0,02
D1 | LED LFO2 | ~ | LED_THT:LED_D3.0mm | 1 |  | 3004Y1D-EHC-B (https://www.reichelt.de/de/de/shop/produkt/led_3mm_bedrahtet_gelb_350_mcd_60_-361904) | 0,08 | 0,08 | gelb
D2 | LED LFO1 | ~ | LED_THT:LED_D3.0mm | 1 |  | 3004Y1D-EHC-B (https://www.reichelt.de/de/de/shop/produkt/led_3mm_bedrahtet_gelb_350_mcd_60_-361904) | 0,08 | 0,08 | gelb
D3 | LED Shift1 | ~ | LED_THT:LED_D3.0mm | 1 |  | 3004Y1D-EHC-B (https://www.reichelt.de/de/de/shop/produkt/led_3mm_bedrahtet_gelb_350_mcd_60_-361904) | 0,08 | 0,08 | gelb
D4 | LED Fire1 | ~ | LED_THT:LED_D3.0mm | 1 |  | 3034B2D-EHD-A | 0,08 | 0,08 | blau
D5 | LED Fire2 | ~ | LED_THT:LED_D3.0mm | 1 |  | 3034B2D-EHD-A | 0,08 | 0,08 | blau
D6 | LED Fire3 | ~ | LED_THT:LED_D3.0mm | 1 |  | 3034B2D-EHD-A | 0,08 | 0,08 | blau
D7 | LED Fire4 | ~ | LED_THT:LED_D3.0mm | 1 |  | 3034B2D-EHD-A | 0,08 | 0,08 | blau
D8 | LED_WF_Squ | ~ | LED_THT:LED_D3.0mm | 1 |  | 3004G6D-EHB-S (https://www.reichelt.de/de/de/shop/produkt/led_3mm_bedrahtet_gruen_200_mcd_60_-361906) | 0,08 | 0,08 | grün
D9 | LED Shift2 | ~ | LED_THT:LED_D3.0mm | 1 |  | 3004R2D-EPC-S (https://www.reichelt.de/de/de/shop/produkt/led_3mm_bedrahtet_rot_100_mcd_60_-361901) | 0,15 | 0,15 | rot
D10 | LED_WF_Tri | ~ | LED_THT:LED_D3.0mm | 1 |  | 3004G6D-EHB-S (https://www.reichelt.de/de/de/shop/produkt/led_3mm_bedrahtet_gruen_200_mcd_60_-361906) | 0,08 | 0,08 | grün
D11 | LED_WF_Saw | ~ | LED_THT:LED_D3.0mm | 1 |  | 3004G6D-EHB-S (https://www.reichelt.de/de/de/shop/produkt/led_3mm_bedrahtet_gruen_200_mcd_60_-361906) | 0,08 | 0,08 | grün
D20 | SK110 | ~ | Diode_SMD:D_SMA-SMB_Universal_Handsoldering | 1 |  |  | 0,02 | 0,02
J1 | AudioJack3_Ground | ~ | Audiosockets:Jack_3.5mm_Ledino_KB3SPRS_Horizontal | 1 |  | EBS 35 | 0,36 | 0,36
J2 | Power Jack | ~ | Connector_BarrelJack:BarrelJack_GCT_DCJ200-10-A_Horizontal | 1 |  | CLIFF FCR681465 | 1,10 | 1,10
R2,R3,R7,R8,R9,R10,R11,R12,R16,R17,R18 | 680 | ~ | Resistor_SMD:R_1206_3216Metric | 11 |  |  | 0,02 | 0,22
R4,R5,R6 | 1k | ~ | Resistor_SMD:R_1206_3216Metric | 3 |  |  | 0,02 | 0,06
R19,R27 | 4,7k | ~ | Resistor_SMD:R_1206_3216Metric | 2 |  |  | 0,02 | 0,04
R20,R21,R26,R28,R29,R30,RV1,RV2,RV3 | 10k | ~ | -- verschiedene Werte -- | 9 |  | RK09K113-LIN10K | 0,99 | 8,91
R22,R25 | 15k | ~ | Resistor_SMD:R_1206_3216Metric | 2 |  |  | 0,02 | 0,04
R23,RV4,RV5 | 100k | ~ | -- verschiedene Werte -- | 3 |  | RK09K113-LIN100K | 0,99 | 2,97
R24 | 5,6k | ~ | Resistor_SMD:R_1206_3216Metric | 1 |  |  | 0,02 | 0,02
RV6 | 50k | ~ | poti_alps:Potentiometer_Alps_RK09K_Single_Vertical | 1 |  | RK09K113-LIN50K | 0,99 | 0,99
SW1 | LFO1/2 | ~ | Button_Switch_THT:SW_PUSH_6mm | 1 |  | OMR B3F-1002 | 0,29 | 0,29
SW2 | Select LFO WaveForm | ~ | Button_Switch_THT:SW_PUSH_6mm | 1 |  | OMR B3F-1002 | 0,29 | 0,29
SW3 | Fire4 | ~ | Button_Switch_THT:SW_PUSH_6mm | 1 |  | RAFI 100.502 | 1,15 | 1,15
SW4 | Fire3 | ~ | Button_Switch_THT:SW_PUSH_6mm | 1 |  | RAFI 100.502 | 1,15 | 1,15
SW5 | Fire2 | ~ | Button_Switch_THT:SW_PUSH_6mm | 1 |  | RAFI 100.502 | 1,15 | 1,15
SW6 | Fire1 | ~ | Button_Switch_THT:SW_PUSH_6mm | 1 |  | RAFI 100.502 | 1,15 | 1,15
SW7 | Shift2/Save | ~ | Button_Switch_THT:SW_PUSH_6mm | 1 |  | OMR B3F-1002 | 0,29 | 0,29
SW8 | Shift1 / Select Bank | ~ | Button_Switch_THT:SW_PUSH_6mm | 1 |  | OMR B3F-1002 | 0,29 | 0,29
U2 | PT2399 |  | Package_DIP:DIP-16_W7.62mm_Socket_LongPads | 1 |  |  | 4,00 | 4,00 | CHINA
U3 | L7805 | http://www.st.com/content/ccc/resource/technical/document/datasheet/41/4f/b3/b0/12/d4/47/88/CD00000444.pdf/files/CD00000444.pdf/jcr:content/translations/en.CD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 | Package_TO_SOT_SMD:TO-252-3_TabPin2 | 1 |  | L78M05CDT STM | 0,21 | 0,21
Power Supply 12V 0,5A |  |  |  | 1 |  | EA1005BHES1201 oder YS6V-1200500E | 7,00 | 7,00
PCB |  |  |  | 1 |  |  | 10,00 | 10,00
Adapter Klinke 3,5mm-6,3mm |  |  |  | 10 |  |  | 2,00 | 20,00
 |  |  |  |  |  |  |  |  | incl. MWST
 |  |  |  |  |  |  | SUMME | 69,31 | 82,4789

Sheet: Screws
Reference | Name | Qty | Bemerkung | Hersteller Partno. | Conrad Orderno. | RS Online
1 | Gewindestift M2 x 4mm | 6 | für Potiknopf | Toolcraft TO-5370165 | 1790055 - NA | 431-965
2 | Zylinderkopf Innensechskantschraube, Stahl schwarz passiviert, M1.6 x 0.35mm, 6mm | 5 | für Leiste |  |  | 304-17-406
3 | Zylinderkopf Innensechskantschraube, Edelstahl A2 , M3 x 0.5mm, 6mm | 7 | Befestigung PCB |  |  | 303-95-067
4 | Senkkopf Innensechskantschraube, Edelstahl DIN 7991 A4, M3 x 0.5mm, 8mm | 4 | Gehäuseschraube |  |  | 304-17-413
 | 4
 | 2 3
 | 1

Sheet: 3D-Print
Position | Name | STL File | Filament Color | Filament Material | QTY
1 | Body | DIYBody_V12.3.stl | Black | PLA | 1
2 | Body bottom | DIYBodyBottomSlim_V12.3.stl | Black | PLA | 1
3 | Functionsbuttons / Shift | DIYKnobShift_V12.2_8mm.stl | White | PLA | 4
4 | Fire Button | DIYKnobFire_V12.3.stl | White | PLA | 4
5 | Fire Button extension | DIYKnobFire - Stößel_V12.3_1.stl | White | PLA | 4
6 | Fire Button Inlay | DIYKnobFire - Inlay_V12.3.stl | White | PLA | 4
7 | stribe for Buttons | DIYBodyStreifen.stl | White or Black or whatever | PLA | 1
8 | Potiknob | PotiKnobV25.stl | Black | PLA | 6
9 | Potiknob Inlay | PotiKnob - Inlays_x10_V12.0.stl | Transparent | PLA | 6
9 |  | 3
 |  | 5
8
 |  | 6
 |  | 4
 |  | 7
1 | 2

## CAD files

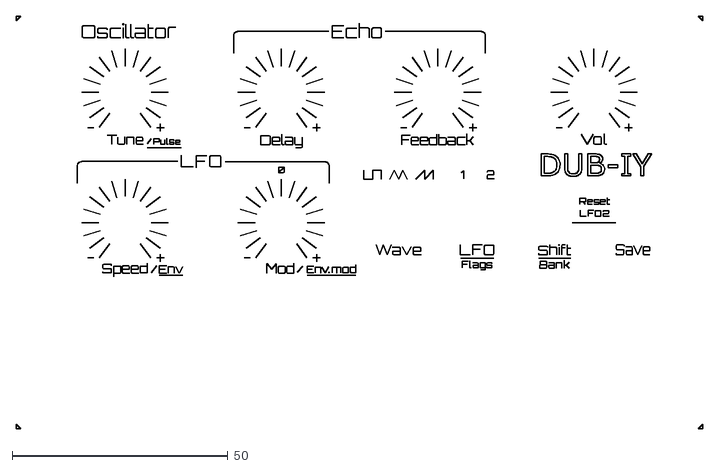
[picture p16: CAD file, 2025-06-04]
CAD/DXF/Frontplatte_EMS_grosse_schriftt_engrave_logo_lasergrbl.dxf
158.9 x 95.5

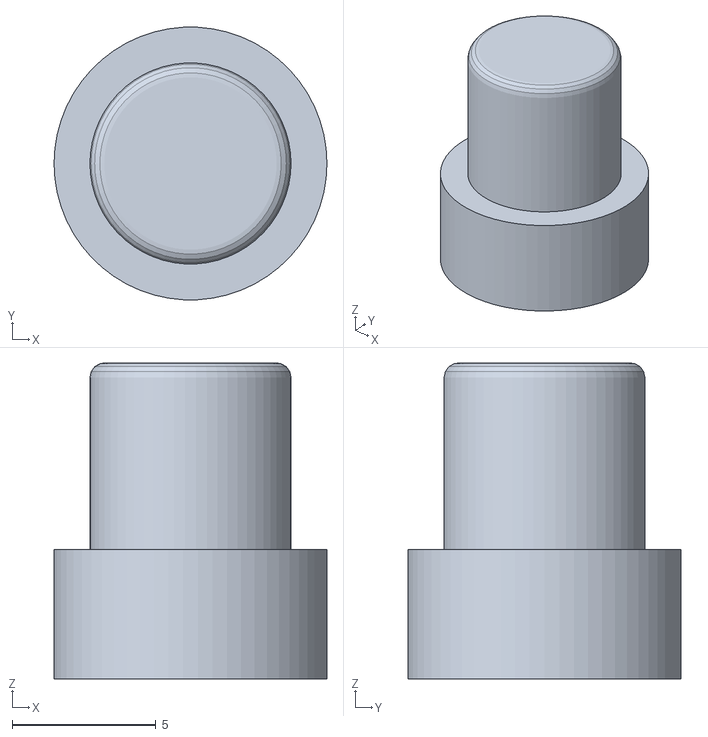
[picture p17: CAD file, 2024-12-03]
CAD/STL/10/DIYKnobShift_V10.1.stl
9.50 x 9.49 x 11.0

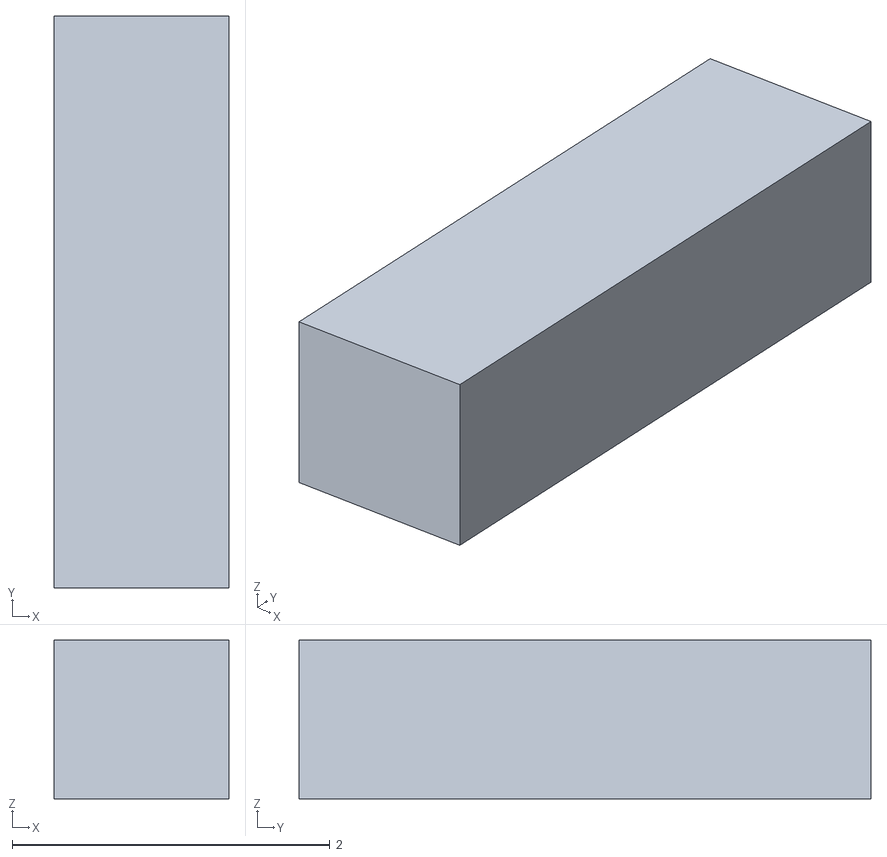
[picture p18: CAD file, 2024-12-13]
CAD/STL/11/PotiKnob_inlay_V11.6.stl
1.10 x 3.60 x 1.00

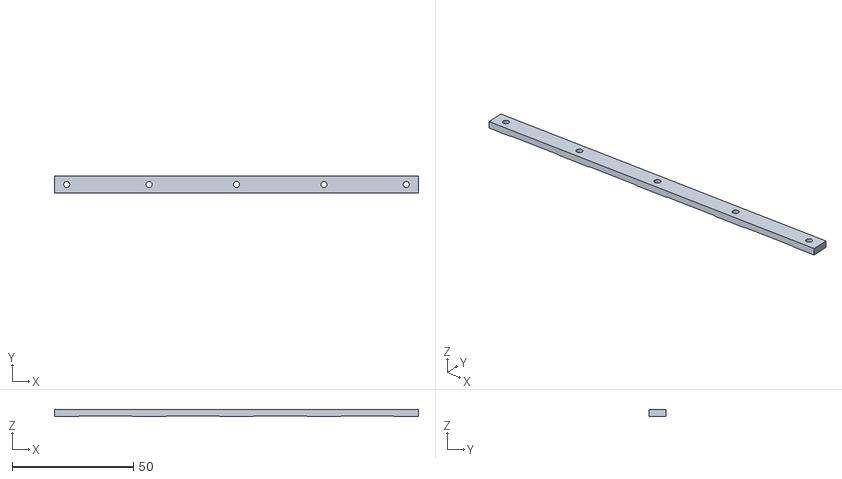
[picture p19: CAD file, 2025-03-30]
CAD/STL/12/DIYBodyStreifen.stl
150.0 x 7.00 x 2.70

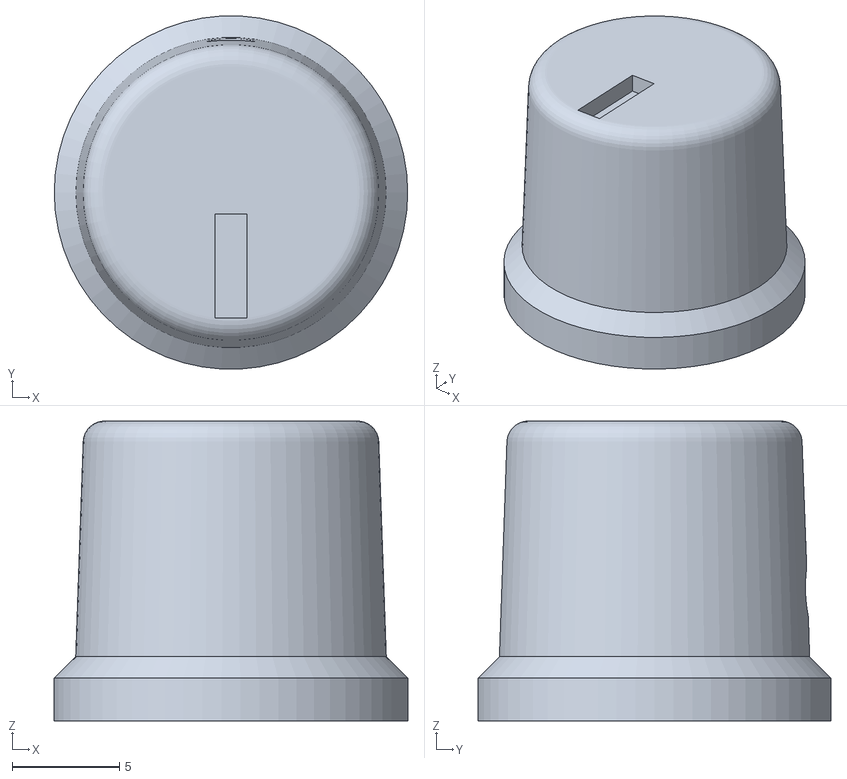
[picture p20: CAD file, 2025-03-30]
CAD/STL/25/PotiKnobV25.stl
16.5 x 16.5 x 14.0

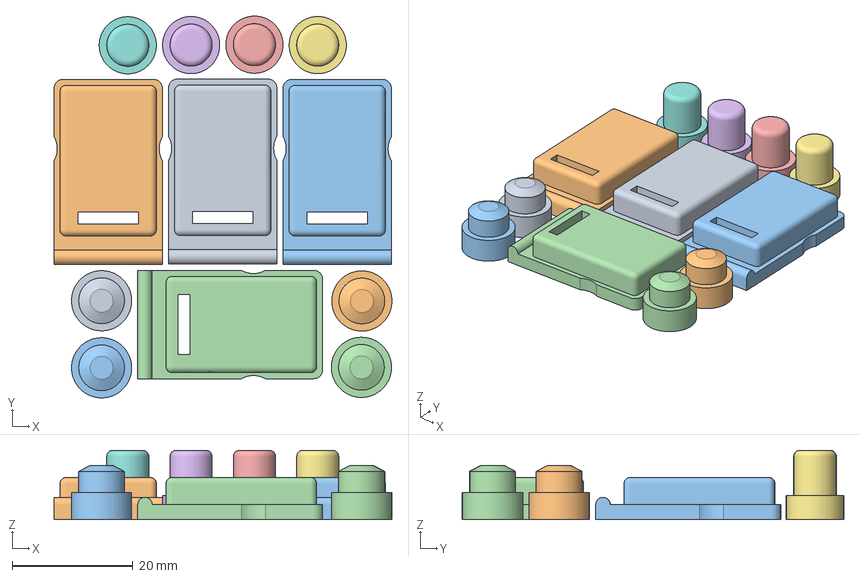
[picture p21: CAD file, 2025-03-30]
CAD/STL/CR10_DIYKnob_V12.3.3mf
56.1 x 63.4 x 11.5 mm
DIYKnobFire_V12.3.stl
DIYKnobFire_V12.3.stl(1)
DIYKnobFire_V12.3.stl(2)
DIYKnobFire_V12.3.stl(3)
DIYKnobShift_V12.2_8mm.stl
DIYKnobShift_V12.2_8mm.stl(1)
DIYKnobShift_V12.2_8mm.stl(2)
DIYKnobShift_V12.2_8mm.stl(3)
DIYKnobFire - Stößel_V12.3.stl
DIYKnobFire - Stößel_V12.3.stl(1)
DIYKnobFire - Stößel_V12.3.stl(2)
DIYKnobFire - Stößel_V12.3.stl(3)

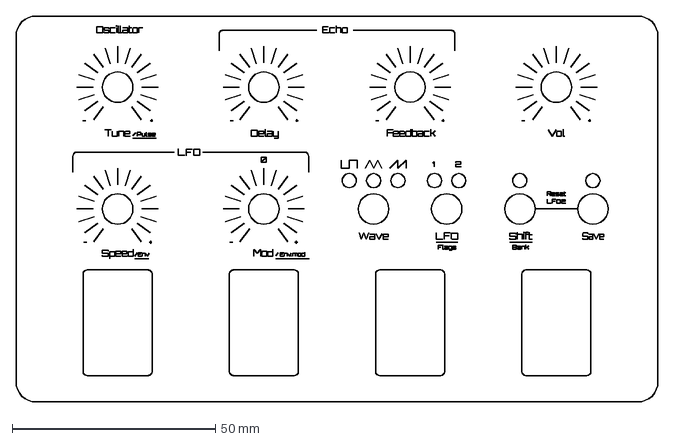
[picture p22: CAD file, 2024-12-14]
CAD/DXF/DIYBody - Frontplatte_EMS_1.dxf
158.0 x 95.0 mm

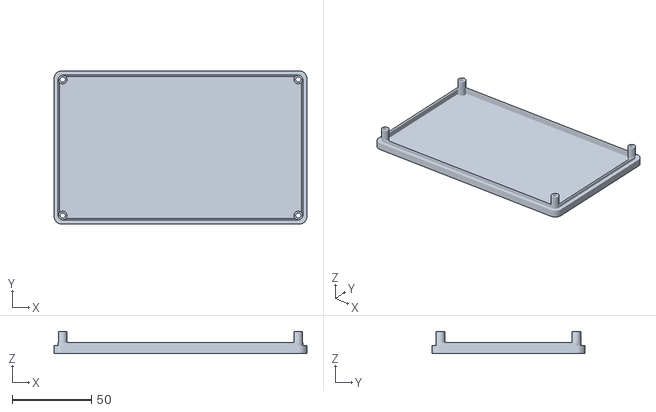
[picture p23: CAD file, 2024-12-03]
CAD/STL/10/DIYDeckel_V10.1.stl
160.0 x 97.0 x 14.0

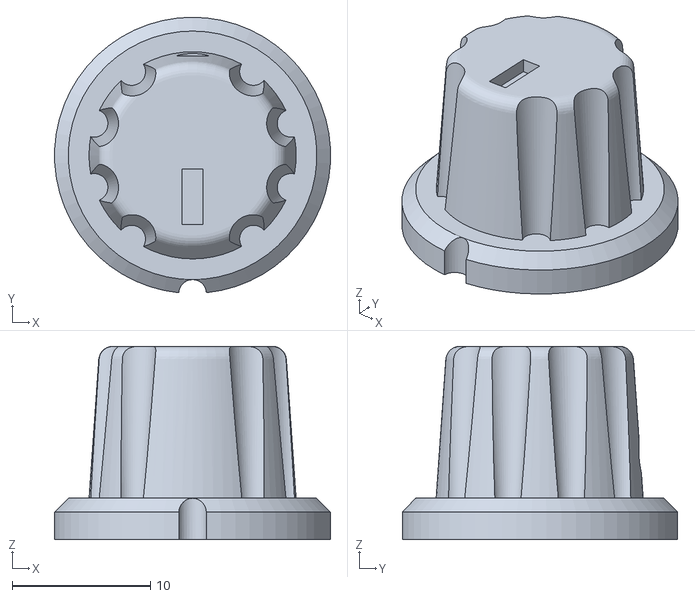
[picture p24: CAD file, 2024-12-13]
CAD/STL/11/PotiKnob_V11.6.stl
20.0 x 19.9 x 14.0

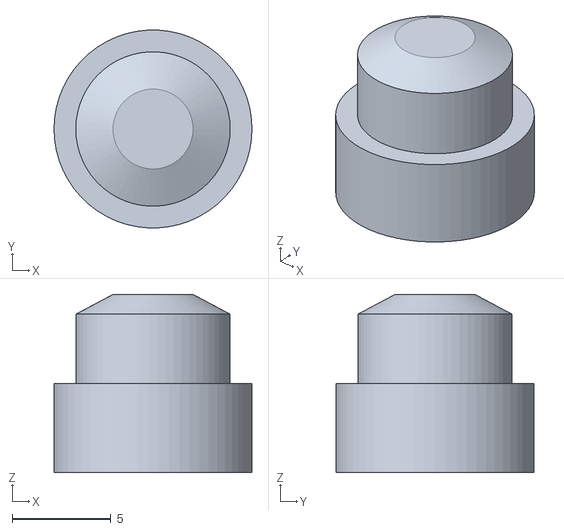
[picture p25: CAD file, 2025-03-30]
CAD/STL/12/DIYKnobFire - Stößel_V12.3_1.stl
10.0 x 9.99 x 9.00

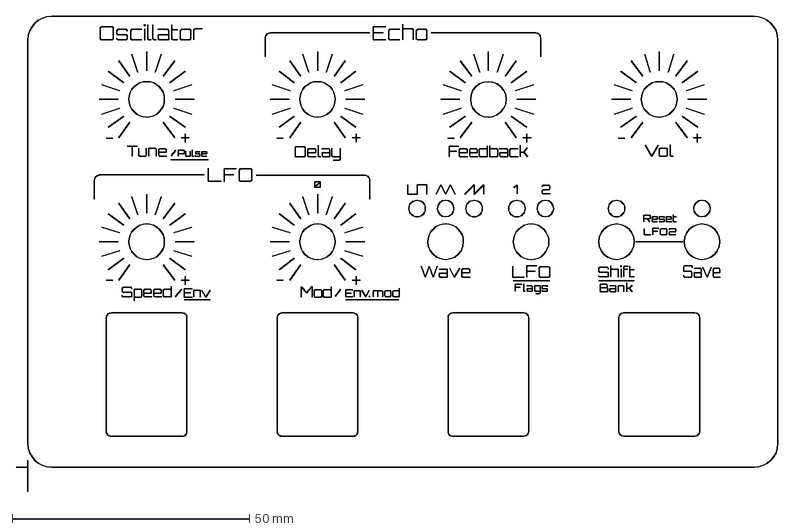
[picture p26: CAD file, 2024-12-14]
CAD/DXF/DIYBody - Frontplatte_EMS_grosse_schrift.dxf
160.5 x 100.2 mm

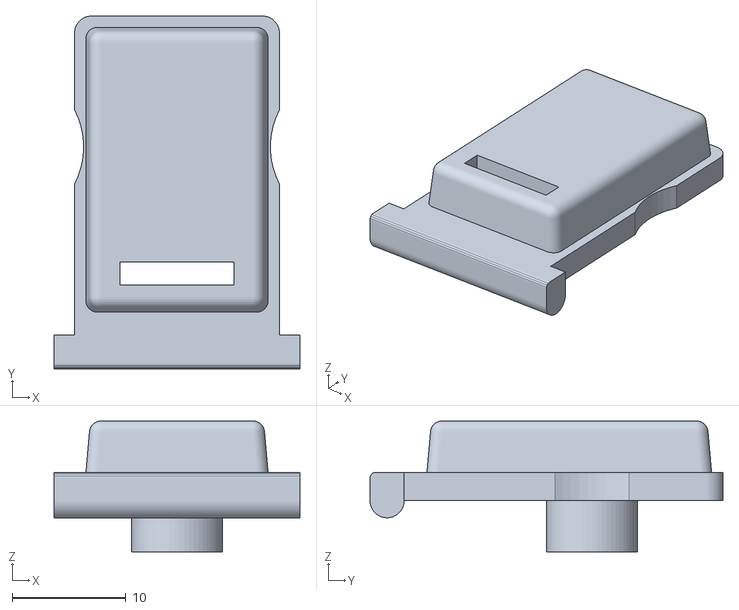
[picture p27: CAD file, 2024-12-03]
CAD/STL/10/DIYKnobFireSquare_V10.1.stl
21.6 x 31.0 x 11.5

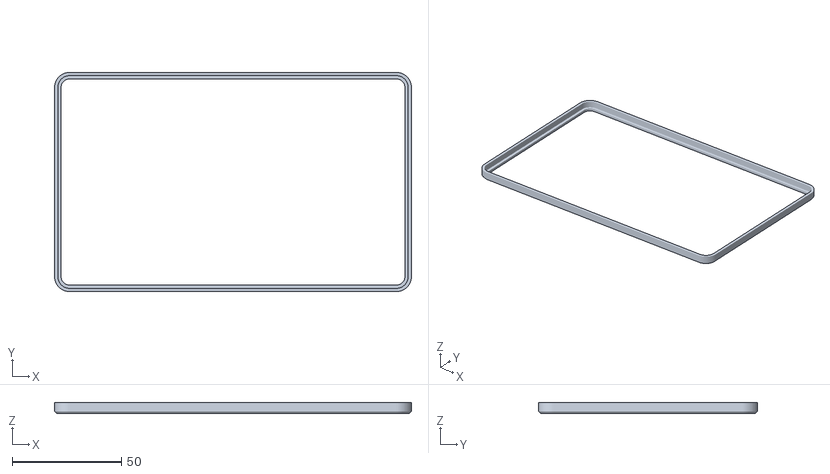
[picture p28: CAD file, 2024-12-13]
CAD/STL/11/DIYBody - Rahmen.stl
163.4 x 100.4 x 5.00

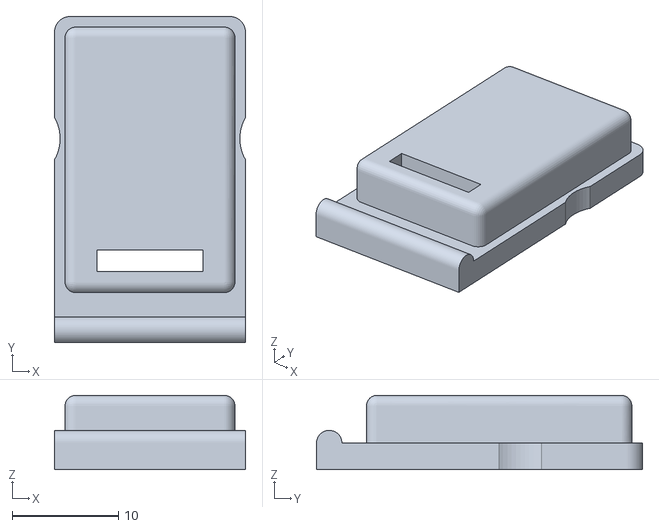
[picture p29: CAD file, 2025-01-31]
CAD/STL/12/DIYKnobFire_V12.3.stl
18.0 x 30.7 x 7.00

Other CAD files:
CAD/DXF/DIYBody - Frontplatte_EMS.dxf
CAD/STL/10/DIYStreifen_V10.1.stl
CAD/STL/11/DIYKnobShift_V11.3.stl
CAD/DXF/DIYBody - Frontplatte.dxf
CAD/STL/10/DIYKnob Fire - Inlay square.stl
CAD/STL/11/DIYDeckel_V11.1_10mm.stl
CAD/STL/11/DIYDeckel_V11.4_15mm.stl
CAD/STL/11/DIYDeckel_V11.4_5mm.stl
CAD/STL/11/DIYKnobFireInlaysquare_V11.1.stl
CAD/STL/11/DIYKnobFireStößel_V11.2.stl
CAD/STL/11/DIYKnobFiresquare_V11.3.stl
CAD/STL/11/DIYStreifen_V11.3.stl
CAD/STL/12/DIYBodyBottomSlim_V12.1.stl
CAD/STL/12/DIYBodyBottomSlim_V12.3.stl
CAD/STL/12/DIYKnobFire - Inlay_V12.3.stl
CAD/STL/12/DIYKnobFire - Stößel_V12.3.stl
CAD/STL/12/DIYKnobShift_V12.2_8mm.stl
CAD/STL/12/PotiKnob - Inlays_x10_V12.0.stl
CAD/STL/12/PotiKnob_V12.4.stl

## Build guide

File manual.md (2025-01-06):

# Short manual key assignment

* load and play tone: Fire Button
* save tone to internal memory: Save Button + Fire Button
* Adjust LFO Waveform: Waveform
* choose LFO1 or LFO2: LFO




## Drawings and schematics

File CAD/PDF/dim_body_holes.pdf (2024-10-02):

2
1

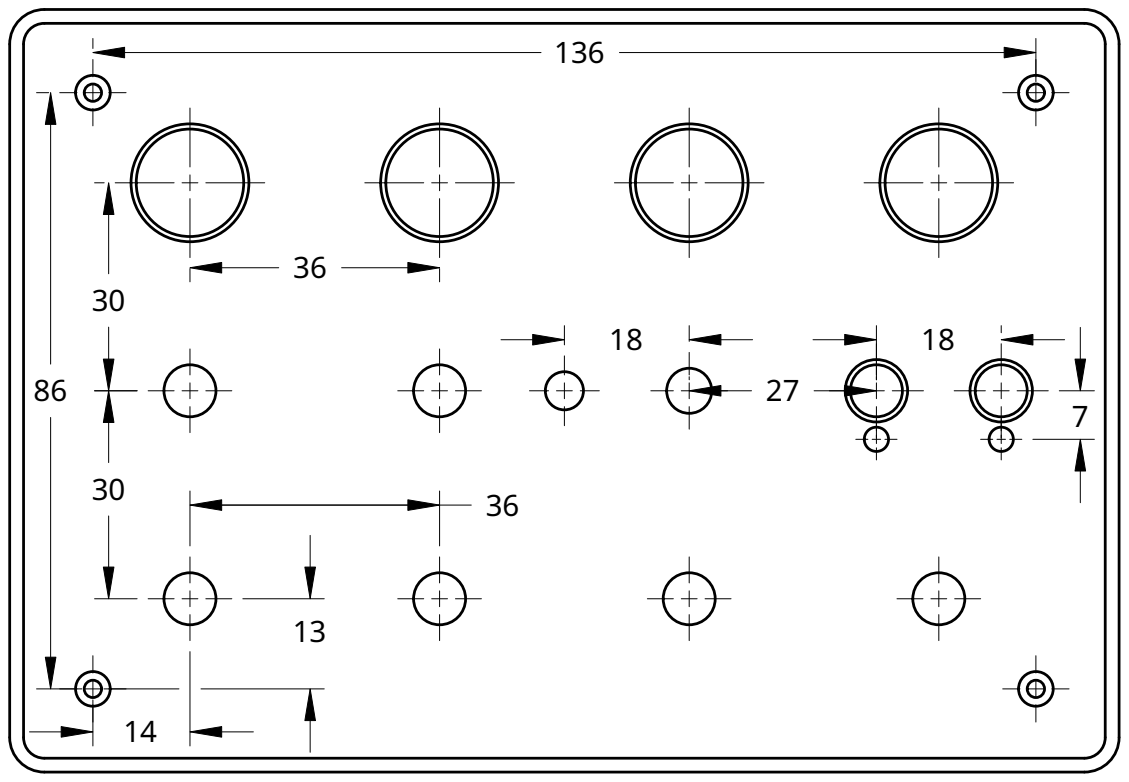
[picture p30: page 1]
MATERIAL; FINISH

UNLESS OTHERWISE SPECIFIED, DIMENSIONS ARE IN MILLIMETERS ANGULAR = ± ° SURFACE FINISH | | NAME | DATE

DRAWN | DIRK HANISCH | 09/30/2024

CHECKED | | | TITLE

APPROVED

DO NOT SCALE DRAWING

BREAK ALL SHARP EDGES AND

REMOVE BURRS
THIRD ANGLE PROJECTION

SIZE A | DWG NO. | REV.

SCALE 1:1 | WEIGHT | SHEET 1 of 1

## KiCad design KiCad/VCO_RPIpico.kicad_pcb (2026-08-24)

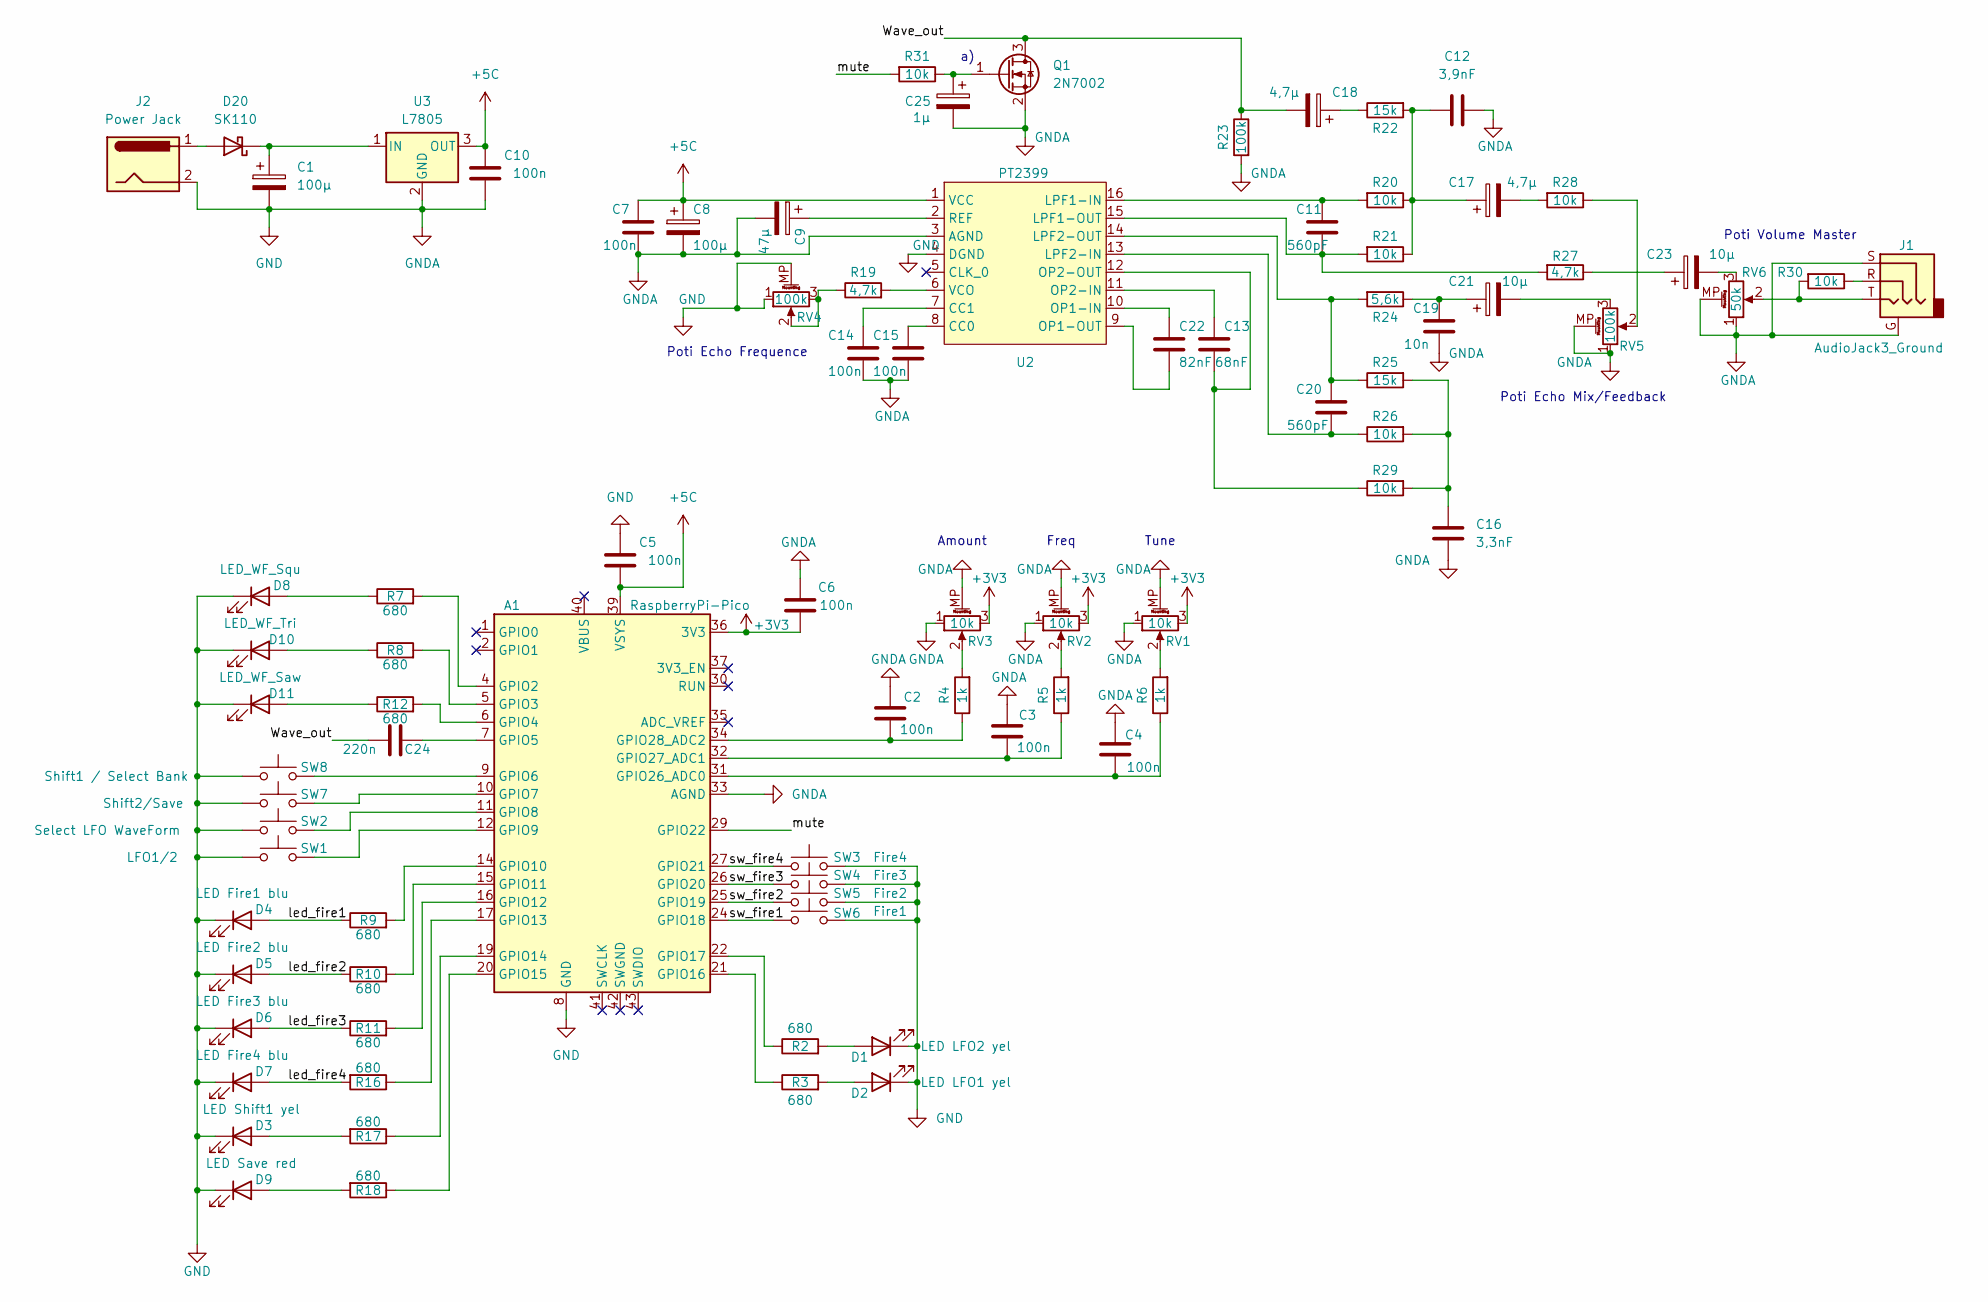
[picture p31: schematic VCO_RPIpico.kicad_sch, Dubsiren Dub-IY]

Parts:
A1: RaspberryPi-Pico; RPi_Pico_SMD_TH
C1, C8: 100µ; CP_Elec_6.3x5.8
C2, C3, C4, C5, C6, C7: 100n; C_1206_3216Metric
C9: 47µ; CP_Elec_6.3x5.3
C10, C14, C15: 100n; C_0805_2012Metric_Pad1.18x1.45mm_HandSolder
C11, C20: 560pF; C_0805_2012Metric_Pad1.18x1.45mm_HandSolder
C12: 3,9nF; C_0805_2012Metric_Pad1.18x1.45mm_HandSolder
C13: 68nF; C_0805_2012Metric_Pad1.18x1.45mm_HandSolder
C16: 3,3nF; C_0805_2012Metric_Pad1.18x1.45mm_HandSolder
C17, C18: 4,7µ; CP_EIA-2012-12_Kemet-R_Pad1.30x1.05mm_HandSolder
C19: 10n; C_0805_2012Metric_Pad1.18x1.45mm_HandSolder
C21, C23: 10µ; CP_Elec_4x5.7
C22: 82nF; C_0805_2012Metric_Pad1.18x1.45mm_HandSolder
C24: 220n; C_1206_3216Metric
C25: 1µ; CP_EIA-2012-12_Kemet-R_Pad1.30x1.05mm_HandSolder
D1: LED LFO2 yel; LED_D3.0mm
D2: LED LFO1 yel; LED_D3.0mm
D3: LED Shift1 yel; LED_D3.0mm
D4: LED Fire1 blu; LED_D3.0mm
D5: LED Fire2 blu; LED_D3.0mm
D6: LED Fire3 blu; LED_D3.0mm
D7: LED Fire4 blu; LED_D3.0mm
D8: LED_WF_Squ; LED_D3.0mm
D9: LED Save red; LED_D3.0mm
D10: LED_WF_Tri; LED_D3.0mm
D11: LED_WF_Saw; LED_D3.0mm
D20: SK110; D_SMA-SMB_Universal_Handsoldering
J1: AudioJack3_Ground; Jack_6.35mm_Neutrik_NMJ6HFD2_Horizontal
J2: Power Jack; BarrelJack_GCT_DCJ200-10-A_Horizontal
Q1: 2N7002; SOT-23
R2, R3, R7, R8, R9, R10, R11, R12, R16, R17, R18: 680; R_1206_3216Metric
R4, R5, R6: 1k; R_1206_3216Metric
R19, R27: 4,7k; R_1206_3216Metric
R20, R21, R26, R28, R29, R30, R31: 10k; R_1206_3216Metric
R22, R25: 15k; R_1206_3216Metric
R23: 100k; R_1206_3216Metric
R24: 5,6k; R_1206_3216Metric
RV1, RV2, RV3: 10k; Potentiometer_Alps_RK09K_Single_Vertical
RV4, RV5: 100k; Potentiometer_Alps_RK09K_Single_Vertical
RV6: 50k; Potentiometer_Alps_RK09K_Single_Vertical
SW1: LFO1/2; SW_PUSH_6mm
SW2: Select LFO WaveForm; SW_PUSH_6mm
SW3: Fire4; SW_PUSH_6mm
SW4: Fire3; SW_PUSH_6mm
SW5: Fire2; SW_PUSH_6mm
SW6: Fire1; SW_PUSH_6mm
SW7: Shift2/Save; SW_PUSH_6mm
SW8: Shift1 / Select Bank; SW_PUSH_6mm
U2: PT2399; DIP-16_W7.62mm_Socket_LongPads
U3: L7805; TO-252-3_TabPin2

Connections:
+3V3: A1.36 (3V3), C6.2, RV1.3, RV2.3, RV3.3
+5C: A1.39 (VSYS), C5.2, C7.1, C8.1, C10.1, U2.1 (VCC), U3.3 (OUT)
/Wave_out: C18.2, C24.1, Q1.3 (D), R23.1
/led_fire1: D4.2 (A), R9.1
/led_fire2: D5.2 (A), R10.1
/led_fire3: D6.2 (A), R11.1
/led_fire4: D7.2 (A), R16.2
/sw_fire1: A1.24 (GPIO18), SW6.1
/sw_fire2: A1.25 (GPIO19), SW5.1
/sw_fire3: A1.26 (GPIO20), SW4.1
/sw_fire4: A1.27 (GPIO21), SW3.1
GND: A1.3 (GND), A1.8 (GND), A1.13 (GND), A1.18 (GND), A1.23 (GND), A1.28 (GND), A1.33 (AGND), A1.38 (GND), C1.2, C2.1, C3.1, C4.1, C5.1, C6.1, C7.2, C8.2, C9.2, C10.2, C12.1, C14.2, C15.2, C16.2, C19.2, C25.2, D1.1 (K), D2.1 (K), D3.1 (K), D4.1 (K), D5.1 (K), D6.1 (K), D7.1 (K), D8.1 (K), D9.1 (K), D10.1 (K), D11.1 (K), J1.G, J1.S, J2.2, Q1.2 (S), R23.2, RV1.1, RV1.MP (MountPin), RV2.1, RV2.MP (MountPin), RV3.1, RV3.MP (MountPin), RV4.1, RV4.MP (MountPin), RV5.1, RV5.MP (MountPin), RV6.1, RV6.MP (MountPin), SW1.1, SW2.1, SW3.2, SW4.2, SW5.2, SW6.2, SW7.1, SW8.1, U2.3 (AGND), U2.4 (DGND), U3.2 (GND)
unnamed: A1.4 (GPIO2), R7.2
unnamed: A1.5 (GPIO3), R8.2
unnamed: A1.6 (GPIO4), R12.2
unnamed: A1.7 (GPIO5), C24.2
unnamed: A1.9 (GPIO6), SW8.2
unnamed: A1.10 (GPIO7), SW7.2
unnamed: A1.11 (GPIO8), SW2.2
unnamed: A1.12 (GPIO9), SW1.2
unnamed: A1.14 (GPIO10), R9.2
unnamed: A1.15 (GPIO11), R10.2
unnamed: A1.16 (GPIO12), R11.2
unnamed: A1.17 (GPIO13), R16.1
unnamed: A1.19 (GPIO14), R17.1
unnamed: A1.20 (GPIO15), R18.1
unnamed: A1.21 (GPIO16), R3.1
unnamed: A1.22 (GPIO17), R2.1
unnamed: A1.31 (GPIO26_ADC0), C4.2, R6.1
unnamed: A1.32 (GPIO27_ADC1), C3.2, R5.1
unnamed: A1.34 (GPIO28_ADC2), C2.2, R4.1
unnamed: C12.2, C17.1, R20.1, R21.1, R22.2
unnamed: C16.1, R25.2, R26.2, R29.2
unnamed: C17.2, R28.2
unnamed: C18.1, R22.1
unnamed: C19.1, C21.1, R24.1
unnamed: C21.2, RV5.3
unnamed: C23.1, R27.1
unnamed: C23.2, RV6.3
unnamed: C25.1, Q1.1 (G), R31.1
unnamed: D1.2 (A), R2.2
unnamed: D2.2 (A), R3.2
unnamed: D3.2 (A), R17.2
unnamed: D8.2 (A), R7.1
unnamed: D9.2 (A), R18.2
unnamed: D10.2 (A), R8.1
unnamed: D11.2 (A), R12.1
unnamed: D20.2 (A), J2.1
unnamed: C1.1, D20.1 (K), U3.1 (IN)
unnamed: J1.R, R30.1
unnamed: J1.T, R30.2, RV6.2
unnamed: R4.2, RV3.2
unnamed: R5.2, RV2.2
unnamed: R6.2, RV1.2
unnamed: R19.1, RV4.2, RV4.3
unnamed: R28.1, RV5.2
unnamed: A1.29 (GPIO22), R31.2
unnamed: C15.1, U2.8 (CC0)
unnamed: C14.1, U2.7 (CC1)
unnamed: C11.1, R20.2, U2.16 (LPF1-IN)
unnamed: C11.2, R21.2, R27.2, U2.15 (LPF1-OUT)
unnamed: C20.2, R26.1, U2.13 (LPF2-IN)
unnamed: C20.1, R24.2, R25.1, U2.14 (LPF2-OUT)
unnamed: C22.1, U2.10 (OP1-IN)
unnamed: C22.2, U2.9 (OP1-OUT)
unnamed: C13.1, U2.11 (OP2-IN)
unnamed: C13.2, R29.1, U2.12 (OP2-OUT)
unnamed: C9.1, U2.2 (REF)
unnamed: R19.2, U2.6 (VCO)

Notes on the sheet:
Poti Echo Mix/Feedback
Freq
Poti Echo Frequence
Tune
Poti Volume Master
Amount

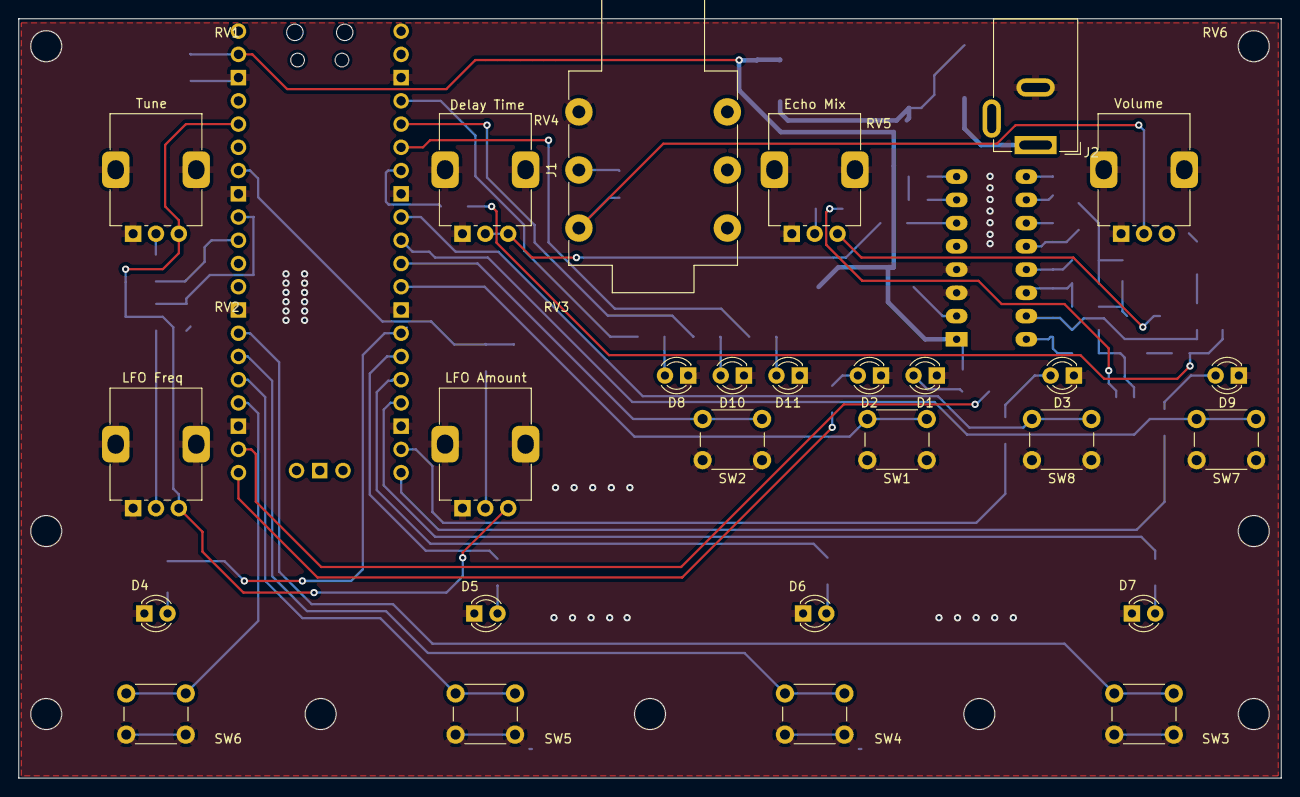
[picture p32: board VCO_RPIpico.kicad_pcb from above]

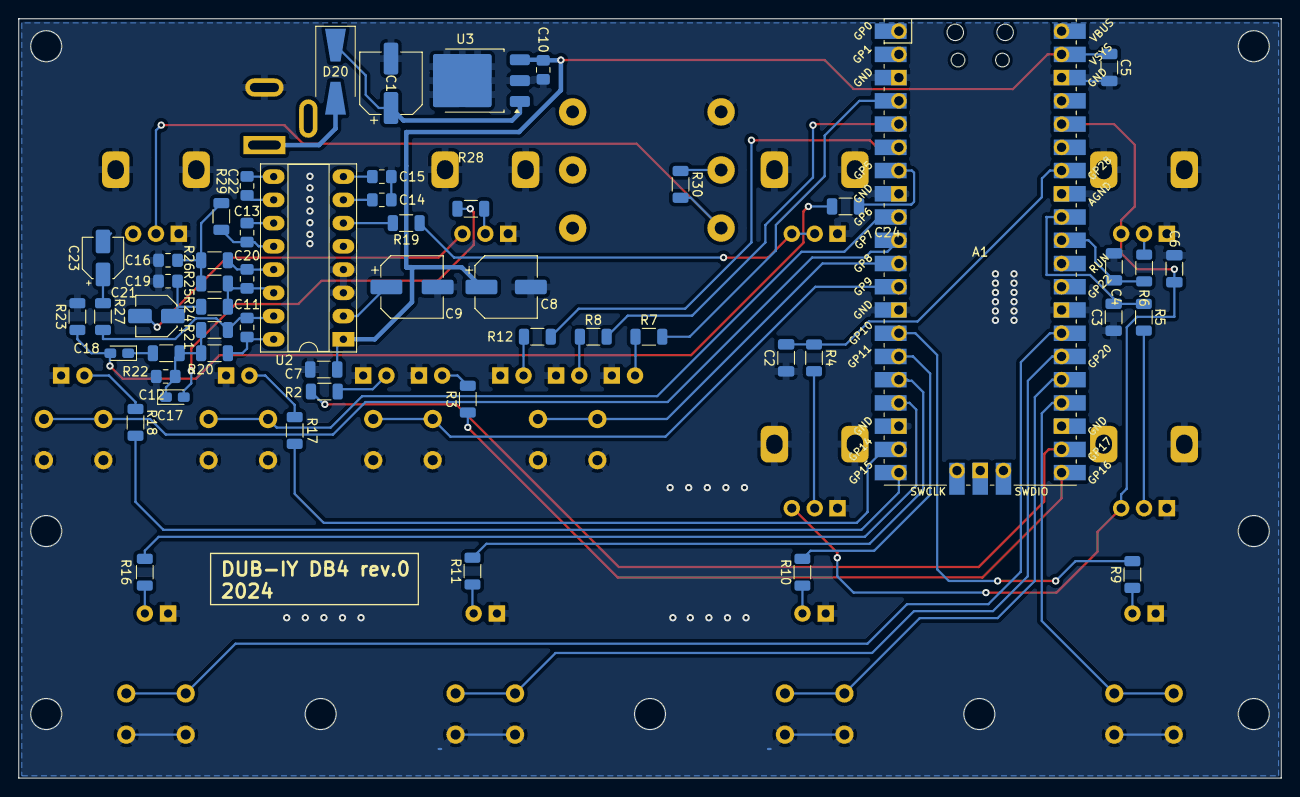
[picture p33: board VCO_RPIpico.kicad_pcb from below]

Board: 2 copper layers, 138.0 x 83.0 mm, 81 parts (54 on the bottom side), 67 nets.

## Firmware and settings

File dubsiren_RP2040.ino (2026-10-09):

#include "pico/stdlib.h"
#include "hardware/pwm.h"
#include "math.h"
#include "LittleFS.h"
#include "Bounce2.h"
#include "ArduinoJson.h"
#include "Wire.h"
#include "GyverOLED.h"

// OLED Display
GyverOLED<SSD1306_128x64, OLED_BUFFER> oled;

// #define LONG_PRESS_DURATION 3000

// Version
#define VER "1.2"

const byte LOGLEVEL = 1;

// Definition der IO's
const int freqPotPin = A0;
const int lfoFreqPotPin = A1;  // Potentiometer für die Frequenz des LFO
const int lfoAmpPotPin = A2;   // Potentiometer für die Amplitude des LFO

const int wave_outputPin = 5; // Pin, an dem der Rechteckton ausgegeben wird
const int wave_mutePin = 22; // Pin zum Muten des Ausgangssignals


const int shiftPin1 = 6;  // shift-Button : Envelope / Bank Select (during hold)
const int shiftPin2 = 7;  // SAVE Button
const int selectWaveFormPin = 8; // WaveForm Select Button
const int selectLFOPin = 9;  // Togglebutton LFO Source / Toggle Special Flags (during hold)


const int firePin1 = 18;  // Steuerpin für die Tonaktivierung1
const int firePin2 = 19;  // Steuerpin für die Tonaktivierung2
const int firePin3 = 20;  // Steuerpin für die Tonaktivierung3
const int firePin4 = 21;  // Steuerpin für die Tonaktivierung4


// LED 
const int LEDLfo1 = 17; 
const int LEDLfo2 = 16;
const int LEDShift1 = 14;
const int LEDSave = 15;

const int LEDFire1 = 10;
const int LEDFire2 = 11;
const int LEDFire3 = 12;
const int LEDFire4 = 13;

const int LEDWaveSquare = 2;
const int LEDWaveTri = 3;
const int LEDWaveSaw = 4;


// Variablen/Konstanten for display
unsigned long previousMillisDisplay = 0;  

const int OLED_GRAPH_X_MIN = 1;
const int OLED_GRAPH_X_MAX = 126;
const int OLED_GRAPH_Y_MIN = 12;
const int OLED_GRAPH_Y_MAX = 54;

float waveformDisplay[128];

byte activeLedRow = 0;
byte activeLedCol = 0;

// Bounce Objekte erstellen zur Tastenabfrage
Bounce fire1;
Bounce fire2;
Bounce fire3;
Bounce fire4;
Bounce selectLFO;
Bounce shift1;
Bounce shift2;
Bounce selectWaveForm;


byte actualFireButton = 0;
byte actualFireButtonBak = 0;
byte lastFireButtonPressed = 0;

// 4 Bänke * 4 FireButtons = 16 Speicherplätze;
byte bank = 1;
byte bankBak = 1;

// Zeitmessung, ob die Firebutton lange gedrückt sind
unsigned long firePressedTime = 0;
bool longPressDetected = false;

// globale V. für Schalter für WaveForm, wo der Wert reinwandert, egal ob per Taster oder Kippschalter
byte valLfoWaveformSwitch = 0;
// temporärer  Wertes des Waveformschalters zum detektieren der Statusänderung
byte valLfoWaveformSwitchBak = 0;


// Konstanten für den minimalen und maximalen Wert der blanken Frequenz ohne Modulation
const float minVal = 35;
const float maxVal = 8000;
// minimaler und maximaler Wert der Frequenz nach der LFO-Modulation
const float minValMod = 20;
const float maxValMod = 16000;

// Variablen
int zaehler = 0;     

// Parameter Pitch/Tune
int baseFrequency = 1000;

// Parameter LFO:
float lfo1Frequency = 5;  // LFO1-Frequenz in Hz (0.5 Hz = 2 Sekunden Periode)
float lfo1Amplitude = 0;

// Parameter LFO2:
float lfo2Frequency = 5;  // LFO2-Frequenz in Hz 
float lfo2Amplitude = 0;

// Parameter ENVELOPE-Generator:
float envelopeDuration = 1;  
float envelopeAmplitude = 0;

float duty = 50;

// die aktuellen Werte für Envelope und LFO
float envelope = 1;
float lfo1ValueActual = 1;
float lfo2ValueActual = 1;

// die finale LFO WaveForm Variable, die durch Schalter oder Speicher gesetzt wird
enum eLfoWaveform { SQUARE, TRIANGLE, SAWTOOTH };
eLfoWaveform lfo1Waveform = TRIANGLE;  //
eLfoWaveform lfo2Waveform = SQUARE;  //

bool dataSaved = false;

// globale Variablen, die der LFO und envelope zurückgibt

volatile float lfo1Value = 0;
volatile float lfo2Value = 0;
volatile float envelopeValue = 1;
volatile int lfo1Direction = 1;  // Richtung des LFO: 1 aufwärts, -1 abwärts
volatile int lfo2Direction = 1;  // Richtung des LFO: 1 aufwärts, -1 abwärts

volatile unsigned long previousMillisLFO1 = 0;
volatile unsigned long previousMillisLFO2 = 0;
volatile unsigned long previousMillisEnv = 0;
volatile unsigned long previousMillisLED = 0;
// volatile unsigned long previousMillisLEDPoll = 0;

volatile float lfovalue_finalLFO1 = 0;
volatile float lfovalue_finalLFO2 = 0;

//volatile int lfo2Stop = 0;
//volatile int lfo1PeriodenCounter = 0;


// Wenn Ton abgefeuert werden soll:
bool runSound = 1;

// bool oledRefresedWhileRunSound = 0;

// shiftToggle-taste
bool lfoToggleState = 0;
bool shiftToggleStateBak = 0;

// shiftState: Byte, in dem eine Kombination aus Shift1 und Shift2 gespeichert wird
byte shiftState = 0;
byte shiftStateBak = 0;

// Modulationsselektor: 0:LFO1, 1: LFO2, 2:Envelope
// wird gesetzt bei pos. Flange LFO1 oder LFO2 oder neg.Flange Shift1
byte modSelect = 0; 
byte modSelectBak = 0;


bool blinkState = 0;
bool blinkState_slow = 0;
byte blinkCounter1 = 0;

// LEDs Firebutton 1 aus 4 mit Status an oder aus
byte selectedFireLed = 0;
bool selectedFireLedState = 0;

// LED1+2

int pwm_led = 1000;

/////////// Definition der Werte, die von den 3 Potis gelesen werden
int valPotiPitch = 0;
int valPotiFreqLFO = 0;
int valPotiAmpLFO = 0;

// temporäre Sicherung der Werte der Potis zum Vergleich, obs gewackelt hat
int valPotiPitchBak = 0;
int valPotiFreqLFOBak = 0;
int valPotiAmpLFOBak = 0;

// Soft-Start gegen Knacken beim Tonbeginn
const float SOFT_START_DUTY = 2.0;            // Start-Duty in %
const unsigned long SOFT_START_US = 15000;    // Dauer der Rampe in µs (xx ms)
bool toneActive = false;                      // läuft der Ton gerade?
unsigned long toneStartMicros = 0;

//  Flags zum ein/Ausschalten von diversen Optionen

byte optionFlags = 0b0000000;  // binär x,x,x,x,x,x,x,Retrigger LFO2
// 0b00000001 : Restart LFO2 on Firepress
// 0b00000010 : One-Time Shot (LFO1)
// 0b00000100 : LFO1 Factor Double Amp

// wie viel Prozent darf sich das Poti ändern, bis ein wert als geändert gilt?
const int potiTolerance = 10;

// Flags, ob sich ein Wert geändert hat
bool potiPitchChanged = false;
bool potiFreqLFOChanged = false;
bool potiAmpLFOChanged = false;

// Letzte Werte ausschließlich für die OLED-Bewegungserkennung
int oledPotiPitchBak = 0;
int oledPotiFreqLFOBak = 0;
int oledPotiAmpLFOBak = 0;


// Display-Refresh
bool displayDirty = true;                         // true = beim Start einmal zeichnen
bool displayForce = false;                        // Erzwingen des Display-refresh
unsigned long displaySettleTime = 0;              // Zeitpunkt für den "Nachlauf"-Refresh
const unsigned long OLED_UPDATE_INTERVAL = 100;   // Mindestabstand zwischen zwei Redraws
const unsigned long OLED_SETTLE_DELAY    = 200;   // Nachlauf nach der letzten Potibewegung

bool lfo1WaveformChanged = false;

String debugString = "";

String receiveStr = ""; // Hier wird die empfangene Zeichenkette gespeichert
bool receiveStrComplete = false;
/////////////////////////////////////////////////////////////////////////////////////////////////////
// Beispiel

// 18:00:44.574 -> read file fire1.json: {"pitch":761,"lfoFreq":9.544205,"lfoAmount":97,"lfo2Freq":9.209431,"lfo2Amount":100,"waveform":2,"waveform2":1,"dutyCycle":50}

// 18:00:44.574 -> read file fire2.json: {"pitch":786,"lfoFreq":25.25,"lfoAmount":49,"lfo2Freq":3.247249,"lfo2Amount":0,"waveform":0,"waveform2":0,"dutyCycle":50}

// 18:00:44.574 -> read file fire3.json: {"pitch":968,"lfoFreq":18.19941,"lfoAmount":32,"lfo2Freq":0.197741,"lfo2Amount":100,"waveform":1,"waveform2":1,"dutyCycle":8}

// 18:00:44.574 -> read file fire4.json: {"pitch":1124,"lfoFreq":7.647839,"lfoAmount":34,"lfo2Freq":4.8111,"lfo2Amount":4,"waveform":0,"waveform2":1,"dutyCycle":50}


/////////////////////////////////////////////////////////////////////////////////////////////////////

void setDefaultDataSet(){
  baseFrequency     = 1000;
  lfo1Frequency     = 15;
  lfo1Amplitude     = 0.0;
  lfo2Frequency     = 5.0;
  lfo2Amplitude     = 0.0;
  envelopeDuration  = 2;
  envelopeAmplitude = 0;
  lfo1Waveform      = TRIANGLE;
  lfo2Waveform      = SQUARE;
  duty = 50;
}


// Werte von den Potis und Schaltern in eine JSON datei speicher
String values2JSON(){
  // Erstelle einen JSON-Dokument Puffer mit genügend Speicher
  StaticJsonDocument<200> dataSet;
/*
  // Verschachtelt
  JsonObject actualDataset = doc.createNestedObject(fireButton);
  actualDataset["pitch"]     = baseFrequency;
  actualDataset["lfoFreq"]   = lfo1Frequency;
  actualDataset["lfoAmount"] = lfoAmplitude;
  actualDataset["envTime"]   = envelopeDuration;
  actualDataset["envAmount"] = envelopeAmplitude;
  actualDataset["waveform"] = lfoWaveform;
*/
  // Plain
  dataSet["pitch"]     = baseFrequency;
  dataSet["lfoFreq"]   = lfo1Frequency;
  dataSet["lfoAmount"] = lfo1Amplitude;
  dataSet["lfo2Freq"]   = lfo2Frequency;
  dataSet["lfo2Amount"] = lfo2Amplitude;
  dataSet["envTime"]   = envelopeDuration;
  dataSet["envAmount"] = envelopeAmplitude;
  dataSet["waveform"]  = lfo1Waveform;
  dataSet["waveform2"]  = lfo2Waveform;
  dataSet["dutyCycle"]  = duty;
  dataSet["optionFlags"]  = optionFlags;

  // Erstelle einen JSON-String
  String jsonString;
  serializeJson(dataSet, jsonString);

  // String fileName = fireButton+".json";
  // JSON-String ausgeben
  // return(writeSettings(fileName, jsonString));
  return jsonString;
}

void JSON2values(String jsonString) {
  // Erstelle ein JSON-Dokument für das Parsen
  StaticJsonDocument<200> dataSet;

  // Deserialisiere den JSON-String
  DeserializationError error = deserializeJson(dataSet, jsonString);

  // Überprüfen, ob die Deserialisierung erfolgreich war
  if (error) {
    Serial.print("Fehler beim Parsen: ");
    Serial.println(error.f_str());
    return;
  }


  baseFrequency = dataSet["pitch"];
  lfo1Frequency = dataSet["lfoFreq"];
  lfo1Amplitude = dataSet["lfoAmount"];
  lfo2Frequency = dataSet["lfo2Freq"];
  lfo2Amplitude = dataSet["lfo2Amount"];
  envelopeDuration = dataSet["envTime"];
  envelopeAmplitude = dataSet["envAmount"];
  lfo1Waveform = dataSet["waveform"];
  lfo2Waveform = dataSet["waveform2"];
  duty = dataSet["dutyCycle"];
  optionFlags = dataSet["optionFlags"];
}

String readSettings(String configFile){
    // Daten lesen
    String value;
    File file = LittleFS.open(configFile, "r");
    if (file) {
        //String value = file.read();  // Lese die gespeicherte Zahl
        value = file.readStringUntil('\n');
        //Serial.println("read file "+configFile+": "+value);
        file.close();
    } else {
        //Serial.println("Error during reading of file "+configFile);
        setDefaultDataSet();
        String _json = values2JSON();
        dataSaved = writeSettings(_json,configFile);
    }
  return(value);
}

bool writeSettings(String _json, String configFile){
  // Daten schreiben
  File file = LittleFS.open(configFile, "w");
  if (file) {
      // String in die Datei schreiben
      
      file.println(_json);  // Schreibt den String und fügt einen Zeilenumbruch hinzu
      file.close();
      return(true);
  } else {
    return(false);
  }
}

bool deleteSettings(String configFile){
 // Datei löschen
  if (LittleFS.remove(configFile)) {
    Serial.println("Datei erfolgreich gelöscht.");
    return true;
  } else {
    Serial.println("Datei konnte nicht gelöscht werden!");
    return false;
  }

}

void debug(String s){
  if (LOGLEVEL > 0){
    Serial.println(s);
  }
}

// Serielle Ausgabe eines Float oder int, mit mehr Zeichen als die Standardmethode
void debugFloat(float f){
  if (LOGLEVEL > 0){
    char buffer[10];  // Puffer für die Zeichenkette, stelle sicher, dass er groß genug ist
    dtostrf(f, 6, 4, buffer);  // 6 Zeichen insgesamt, 4 Dezimalstellen
    String myString = String(buffer);
    Serial.println(myString);
  }
}



// Funktion zur Umwandlung einer linearen Eingangsgröße in eine logarithmische Ausgabe
float linearToLogarithmic(float value,float min, float max) {
  
  float percentage = (value - min ) / ((max - min)/100);
  // Überprüfen, ob die Eingabewerte sinnvoll sind
  if (percentage < 0.0) percentage = 0.0;
  if (percentage > 100.0) percentage = 100.0;

  //int rasterpercentage = percentage ;
  
  // Skaliere den Prozentwert auf den Bereich [0, 1]
  float scaledPercentage = percentage / 100.0;

  // Berechne die logarithmische Ausgabe
  // logarithmischer Bereich mit Basis 10
  float logMin = log10(min);
  float logMax = log10(max);
  
  // Interpolieren im logarithmischen Raum
  float logValue = logMin + scaledPercentage * (logMax - logMin);
  
  // Rückkonvertieren in den linearen Raum
  float outputValue = pow(10, logValue);

  
  //debug(String(value)+';'+String(percentage)+';'+String(outputValue));
  return outputValue;
}

// Generators
float calculateEnvelope(float envelopeDuration, float envelopeAmplitude) {

  unsigned long currentMillis = millis();

  // Tatsächlich vergangene Zeit
  float elapsedMillis = currentMillis - previousMillisEnv;
  previousMillisEnv = currentMillis;

  // Geschwindigkeit des Envelope
  float schrittweite_envelope =
    envelopeDuration * elapsedMillis / 5000.0;


  // Envelope-Wert verringern
  envelopeValue -= schrittweite_envelope;

  if (envelopeValue <= 0.0) {
    envelopeValue = 0.0;
  }


  float envelopeValueLog =
    linearToLogarithmic(envelopeValue, 0.0, 1.0);

  float envelope =
    ((envelopeValue - 0.5) * 1.9) *
    (envelopeAmplitude / 100) + 1;

  return envelope;
}


float calculateLFOWave1(float lfoFrequency, float amplitude) {

  unsigned long currentMillis = millis();

  // Tatsächlich vergangene Zeit seit dem letzten LFO-Update
  float elapsedMillis = currentMillis - previousMillisLFO1;
  previousMillisLFO1 = currentMillis;

  // LFO-Schritt entsprechend der tatsächlich vergangenen Zeit
  float schrittweite = lfoFrequency * elapsedMillis / 1000.0;

  switch (lfo1Waveform) {

    case SQUARE:

      // LFO intern als Dreieck laufen lassen
      lfo1Value += schrittweite * lfo1Direction;

      // Auch bei größeren Zeitsprüngen korrekt über die Grenzen gehen
     while (lfo1Value > 1.0 || lfo1Value < 0.0) {
      if (lfo1Value > 1.0) {
        lfo1Value = 2.0 - lfo1Value;
        lfo1Direction = -1;
        //lfo1PeriodenCounter++;
      }

      if (lfo1Value < 0.0) {
        lfo1Value = -lfo1Value;
        lfo1Direction = 1;
        //lfo1PeriodenCounter++;
      }
    }
      

      if(amplitude == -100){
        lfovalue_finalLFO1 = (lfo1Value <= 0.5) ? 0.5 : -100; // -100 = muting

      } else {

        if(amplitude < 0){

          // 3-er Raster
          if(lfo1Value < 0.25){
            lfovalue_finalLFO1 = 0;
          }else if(lfo1Value < 0.75){
            lfovalue_finalLFO1 = 0.5;
          }else {
            lfovalue_finalLFO1 = 1;
          }

        }else{
          lfovalue_finalLFO1 = (lfo1Value >= 0.5) ? 1 : 0;
        }
      }

      break;


    case TRIANGLE:

      lfo1Value += schrittweite * lfo1Direction;

      // Auch bei größeren Zeitsprüngen korrekt über die Grenzen gehen

      while (lfo1Value > 1.0 || lfo1Value < 0.0) {
          if (lfo1Value > 1.0) {
              lfo1Value = 2.0 - lfo1Value;
              lfo1Direction = -1;
              //lfo1PeriodenCounter++;
          }

          if (lfo1Value < 0.0) {
              lfo1Value = -lfo1Value;
              lfo1Direction = 1;
              //lfo1PeriodenCounter++;
          }
      }

      lfovalue_finalLFO1 = lfo1Value;

      break;


    case SAWTOOTH:

      lfo1Value -= schrittweite / 2;

      // Auch bei größeren Zeitsprüngen korrekt über den Anfang springen
      while (lfo1Value <= 0) {
        lfo1Value += 1.0;
        //lfo1PeriodenCounter++;
      }

      lfovalue_finalLFO1 = lfo1Value;

      break;
  }


  // lfovalue_finalLFO1 liegt zwischen 0..1:
  // Verschieben der Mitte auf den Nullpunkt
  // Skalierung mit der LFO-Amplitude
  // Verschieben des Nullpunktes auf 1:
  // Ergebnis kann als Frequenz-Multiplikator verwendet werden

  float lfovalue_final1 = 0;

  if(lfovalue_finalLFO1 == -100){

    // negativ für Sonderfunktionen wie Muting
    lfovalue_final1 = lfovalue_finalLFO1;

  }else{

    lfovalue_final1 =
      ( ((lfovalue_finalLFO1 - 0.5) * 1.5) *
        ((amplitude / 100) *
        (optionFlags & 0b00000100 ? 2 : 1))
      ) + 1.0;
  }

  return(lfovalue_final1);
}
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
void loop() {
  
  updateKeys();
  updatePotis();
  readSerial();

  ///////////////////////////// LFO1 ///////////////////////////
  if(modSelect == 0){
    
    if(lfo1WaveformChanged){
      
      switch (valLfoWaveformSwitch) {
        case 0:
          lfo1Waveform = SQUARE;
          break;
        case 1:
          lfo1Waveform = TRIANGLE;
          break;
        case 2:
          lfo1Waveform = SAWTOOTH;
          break;
      }
      
      //lfo1Waveform = valLfoWaveformSwitch;
    }
    
    // Pitch
    if(potiPitchChanged){
      int freqLin = map(valPotiPitch, 4, 1023, minVal, maxVal );
      baseFrequency =  linearToLogarithmic(freqLin, minVal, maxVal);
      valPotiPitchBak = valPotiPitch;
    }
    // Frequenz
    if(potiFreqLFOChanged){
      lfo1Frequency = mapFloat(valPotiFreqLFO, 5, 1023, 0.5, 50);   // LFO-Frequenzbereich von 0.5 Hz bis 50 Hz
      valPotiFreqLFOBak = valPotiFreqLFO;
    }
    // Amount
    if(potiAmpLFOChanged){
      lfo1Amplitude = map(valPotiAmpLFO, 5, 1023, -100, 100);   // LFO-Amplitudenbereich von 0 bis 100, 50 Mitte
      valPotiAmpLFOBak = valPotiAmpLFO;
    }
  } else if(modSelect == 1){
    ///////////////////////////// LFO2 ///////////////////////////
    if(lfo1WaveformChanged){
      
      switch (valLfoWaveformSwitch) {
        case 0:
          lfo2Waveform = SQUARE;
          break;
        case 1:
          lfo2Waveform = TRIANGLE;
          break;
        case 2:
          lfo2Waveform = SAWTOOTH;
          break;
      }
      
     //lfo2Waveform = valLfoWaveformSwitch;
    }

    // Pitch
    if(potiPitchChanged){
      int freqLin = map(valPotiPitch, 4, 1023, minVal, maxVal );
      baseFrequency = linearToLogarithmic(freqLin, minVal, maxVal);
      valPotiPitchBak = valPotiPitch;
    }
    // Frequenz
    if(potiFreqLFOChanged){
      lfo2Frequency = mapFloat(valPotiFreqLFO, 5, 1023, 0.1, 20);
      valPotiFreqLFOBak = valPotiFreqLFO;
    }
     // Amount
    if(potiAmpLFOChanged){
      lfo2Amplitude = map(valPotiAmpLFO, 5, 1023, -100, 100);
      valPotiAmpLFOBak = valPotiAmpLFO;
    }
  }  else if(modSelect == 2) {
    ///////////////////////////// Envelope für Speed LFO 1 und 2 ///////////////////////////
    if(lfo1WaveformChanged){
      
      switch (valLfoWaveformSwitch) {
        case 0:
          lfo1Waveform = SQUARE;
          break;
        case 1:
          lfo1Waveform = TRIANGLE;
          break;
        case 2:
          lfo1Waveform = SAWTOOTH;
          break;
      }
      
      // lfo1Waveform = valLfoWaveformSwitch;
    }
    
    // Pitch-Poti = Duty-Cycle 
    if(potiPitchChanged){
      duty = map(valPotiPitch, 4, 1023, 5, 50 );
      valPotiPitchBak = valPotiPitch;
    }
    // LFO-Frequenz-Poti = Geschwindigkeit Envelope
    if(potiFreqLFOChanged){
      envelopeDuration = mapFloat(valPotiFreqLFO, 5, 1023, 1, 10);
      valPotiFreqLFOBak = valPotiFreqLFO;
    }
     // Amount-Poti = Amount Envelope auf LFO-Frequenz
    if(potiAmpLFOChanged){
      envelopeAmplitude = map(valPotiAmpLFO, 5, 1023, -100, 100);
      valPotiAmpLFOBak = valPotiAmpLFO;
    }
  }
  // beide Shift-Tasten zugleich gedrückt, Reset LFO2 Werte
  if(shiftState == 3){
    if (lfo2Amplitude != 0 || envelopeAmplitude != 0) {
      requestDisplayUpdate();      // nur einmal, wenn sich wirklich etwas ändert
    }
    lfo2Amplitude = 0;
    envelopeAmplitude = 0;
    resetShiftState();
  }

   // Modulierte Frequenz berechnen

  envelope = calculateEnvelope(envelopeDuration,envelopeAmplitude);
  lfo1ValueActual = calculateLFOWave1(lfo1Frequency * (envelope), lfo1Amplitude);
  //lfo2ValueActual = calculateLFOWave2(lfo2Frequency * (envelope), lfo2Amplitude);
    lfo2ValueActual = calculateLFOWave2(getLfo2Frequency() * (envelope), lfo2Amplitude);
   
   float newModulatedFrequency = 0;
   if(lfo1ValueActual == -100){
    newModulatedFrequency = lfo1ValueActual;
   }else{
    newModulatedFrequency = baseFrequency * lfo1ValueActual * lfo2ValueActual;
   }
   // Reset LFO values if the start button is false
  // Betriebsanzeige
  blink(50);
  // OLED-Display aktualisieren, wenn nötig
  if (displayForce) updateDisplay();
  // Create Tone
  playSound(newModulatedFrequency);
  // Control LED's updaten
  updateLEDs();
  // Normales Zeichnen NACH dem Ton: beim Loslassen ist er dann schon gestoppt
  updateDisplay();
  

  

  // Display aktualisieren

  // Überwachung und Debugprits
  
  // if(chkLoop(1000)){
  //   debug(oledUpdateActive?"OLED-Update ON":"OLED-Update OFF");
  // }
  
  
 

}

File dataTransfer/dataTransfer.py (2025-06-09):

# Helper to load or save memory dumps from DUB-IY
#
# usage: 
# save single slots (firebutton)
# COMMAND: python3 dataTransfer.py -save xx
# xx = 0 - 16
# File will saves as JSON File with prefix receive_xx with autoenumerating prefix and date_time (e.g. receive_15_20250609_220727.json)
#
# save all 16 slots as dump
# COMMAND: python3 dataTransfer.py -save dump
# File will saved as JSON File with prefix receiveDump_xx with autoenumerating prefix and date_time (e.g. receiveDump_20241130.json)
# 
# load single file to one slot
# COMMAND: python3 dataTransfer.py -load xx receive_xx.json
# Content of receive_xx.json will load and store it to slot xx
# 
# load complete DUmpfile to all 16 slots
# COMMAND: python3 dataTransfer.py -load dump receiveDump_xxx.json
# Content of receiveDump_xxx.json will load and store it to slot 1 - 16


import serial
import time
import json
import sys
import os
import argparse
import serial.tools. list_ports
from datetime import datetime

def finde_arduino_port():
    ports = serial.tools.list_ports.comports()
    for port in ports:
        if "Arduino" in port.description or "ttyACM" in port.device or "usbmodem" in port.device:
            return port.device
    return None


def read_json_from_serial(ser):
    buffer = ""
    start_time = time.time()

    while time.time() - start_time < 3:
        if ser.in_waiting:
            buffer += ser.read(ser.in_waiting).decode('utf-8', errors='ignore')
            try:
                obj = json.loads(buffer.strip())
                return obj
            except json.JSONDecodeError:
                continue

    # Wenn kein gültiges JSON empfangen wurde, gib Rohinhalt aus
    print("❌ keine JSON-Antwort empfangen:")
    print("---- ROHDATEN BEGINN ----")
    print(buffer.strip())
    print("---- ROHDATEN ENDE ----")

    raise ValueError("Keine gültige JSON-Antwort erhalten")


def save_json_to_file(data, befehl):
    now = datetime.now().strftime("%Y%m%d_%H%M%S")
    filename = f"{befehl}_{now}.json"
    script_dir = os.path.dirname(os.path.abspath(__file__))
    full_path = os.path.join(script_dir, filename)

    with open(full_path, 'w', encoding='utf-8') as f:
        json.dump(data, f, ensure_ascii=False, indent=2)

    print(f"Dump gespeichert in: {full_path}")


def communicate(port, baudrate=115200, cmds=None):
    try:
        with serial.Serial(port, baudrate, timeout=2) as ser:
            time.sleep(2)

            for eintrag in (cmds or []):
                typ = eintrag[0]

                # ===============  RECEIVE / SAVE  ===============
                if typ == "receive":
                    befehl = eintrag[1]
                    print(f"Sende: {befehl}")
                    ser.reset_input_buffer()
                    ser.write((befehl + '\n').encode())
                    daten = read_json_from_serial(ser)
                    print("Geparst:", daten)
                    save_json_to_file(daten, befehl)

                # ===============  LOAD / SEND FILE  ===============
                elif typ == "load":
                    befehl, datei = eintrag[1], eintrag[2]
                    print(f"Lade '{datei}' nach {befehl}")
                    if not os.path.isfile(datei):
                        print("Datei nicht gefunden:", datei)
                        continue

                    ser.reset_input_buffer()
                    ser.write((befehl + '\n').encode())
                    time.sleep(0.1)                       # optional: kurze Pause
                    with open(datei, "r", encoding="utf-8") as f:
                        daten = json.load(f)  # JSON-Objekt laden

                    json_string = json.dumps(daten, separators=(',', ':'))  # kompaktes JSON
                    slot = befehl.split("_")[1] if "_" in befehl else "?"   # z.B. "load_1" → "1"
                    print(f"slot: {slot}, command: {befehl}")
                    if slot == "dump":
                        payload = f"load({json_string})\n" 
                    else: 
                        payload = f"load({slot}:{json_string})\n"
                    ser.write(payload.encode('utf-8'))
                    print(f"Gesendet: {payload.strip()}")

                    # Inhalt schicken
                    ser.write(b'\n')                      # Terminator
                    print("Datei übertragen.")

                    daten = read_json_from_serial(ser)
                    print("Response Geparst:", daten)

            if not cmds:
                print("Connection established but no Parameters.")
                print("")
                print("# usage: ")
                print("# save single slots (firebutton)")
                print("# COMMAND: python3 dataTransfer.py -save xx")
                print("# xx = 0 - 16")
                print("# File will saves as JSON File with prefix receive_xx with autoenumerating prefix and date_time (e.g. receive_15_20250609_220727.json)")
                print("# ")
                print("# save all 16 slots as dump")
                print("# COMMAND: python3 dataTransfer.py -save dump")
                print("# File will saved as JSON File with prefix receiveDump_xx with autoenumerating prefix and date_time (e.g. receiveDump_20241130.json)")
                print("# ")
                print("# load single file to one slot")
                print("# COMMAND: python3 dataTransfer.py -load xx receive_xx.json")
                print("# Content of receive_xx.json will load and store it to slot xx")
                print("# ")
                print("# load complete Dumpfile to all 16 slots")
                print("# COMMAND: python3 dataTransfer.py -load dump receiveDump_xxx.json")
                print("# Content of receiveDump_xxx.json will load and store it to slot 1 - 16")

    except Exception as e:
        print("Fehler:", e)



if __name__ == "__main__":
    parser = argparse.ArgumentParser(description="DUB-IY JSON-Dump-Receiver")
    parser.add_argument(
        "-save", type=str,
        help="Sendet 'receive_<x>' und speichert JSON (z. B. dump, 1, 2)"
    )
    parser.add_argument(
        "-load", nargs=2, metavar=("SLOT", "FILE"),
        help="Sendet 'load_<slot>' und überträgt <FILE> (z. B. 1 fire.json)"
    )
    args = parser.parse_args()

    befehle = []

    # SAVE (receive_x)
    if args.save:
        slot = args.save
        cmd = "receiveDump" if slot == "dump" else f"receive_{slot}"
        befehle.append(("receive", cmd))          # (Typ, Befehl)

    # LOAD (load_x + Datei)
    if args.load:
        slot, filename = args.load
        # cmd = "loadDump" if slot == "dump" else f"load_{slot}"
        cmd = f"load_{slot}"
        befehle.append(("load", cmd, filename))   # (Typ, Befehl, Datei)



    port = finde_arduino_port()
    if port:
        print("used port:", port)
        communicate(port, cmds=befehle)
    else:
        print("no valid serial port found.")

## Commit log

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2024-09-04 KiCad DAten erfasst
    [VCO_RPIpico.kicad_pcb, VCO_RPIpico.kicad_sch]
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2024-09-12 Teiler für PWM bei LEDs
    [VCO_RPIpico.kicad_sch]
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2024-09-23 Korrektur und KiCad
    [VCO_RPIpico.kicad_sch]
2024-09-27 Schaltung erweitert um 2 Shhifttasten
    [VCO_RPIpico.kicad_sch]
2024-09-27 Schaltung geändert
    [VCO_RPIpico.kicad_sch]
2024-09-27 CAD-Daten aus Onshape
    [Body - Dubsiren_V1.stl, Frontplatte - Frontplatte.stl, KNOB.dwg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]
2024-09-28 Shiftstate als Byte, Reset des env.durch Sh1+2
    [dubsiren_RP2040.ino]
2024-09-30 Kicad Schematic and Board
    [Body - Dubsiren_V1.stl, VCO_RPIpico.kicad_pcb, VCO_RPIpico.kicad_sch]
2024-09-30 PCB and Schematic
    [VCO_RPIpico.kicad_pcb, VCO_RPIpico.kicad_sch]
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2024-10-02 Shift Knob Added
    [Knob Shift.stl]
2024-10-03 LongPress durch Drücken des Nachbarbutton und Save korrigiert
    [dubsiren_RP2040.ino]
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2024-10-14 Kicad weiter, Blink
    [VCO_RPIpico.kicad_pcb, VCO_RPIpico.kicad_sch]
2024-10-14 modifiziertes Boardlayout
    [VCO_RPIpico.kicad_pcb_ohne_firebuttons.kicad_pcb]
2024-10-15 Implement Blink, Test Reset LFO2
    [dubsiren_RP2040.ino]
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2024-10-19 KiCad weiter
    [VCO_RPIpico.kicad_sch]
2024-10-19 vom Kippschalter umgestellt auf Button zur FLO Waveform Auswahl
    [VCO_RPIpico.kicad_sch]
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2024-10-28 KiCad MatrixLED und Bauteil für Echo
    [VCO_RPIpico.kicad_pcb, VCO_RPIpico.kicad_sch]
2024-10-28 Export STL Body
    [Body - Dubsiren_V6.stl, DubsirenBody - Body.step]
2024-10-28 noch ein Export aus CAD
    [Unterschale - Dubsiren_V6.stl]
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2024-11-09 Umgestellt auf einfache LED Pinansteuerung
    [VCO_RPIpico.kicad_pcb, VCO_RPIpico.kicad_sch]
2024-11-11 Kicad PCB
    [VCO_RPIpico.kicad_pcb, VCO_RPIpico.kicad_pcb_ohne_firebuttons.kicad_pcb]
2024-11-12 Echomodul diskret mit PT2399 implementiert
    [VCO_RPIpico.kicad_sch]
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2024-11-13 PCB Layout
    [VCO_RPIpico.kicad_pcb, VCO_RPIpico.kicad_sch]
2024-11-13 PCB neue Taster
    [VCO_RPIpico.kicad_pcb, VCO_RPIpico.kicad_sch, VCO_RPIpico.step]
2024-11-13 PCB fertig, Gerber Export
    [VCO_RPIpico-B_Cu.gbr, VCO_RPIpico-B_Mask.gbr, VCO_RPIpico-B_Paste.gbr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]
2024-11-13 zusätzliche LEDs unter die kleinen FIre-Button
    [VCO_RPIpico-B_Cu.gbr, VCO_RPIpico-B_Mask.gbr, VCO_RPIpico-B_Paste.gbr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]
2024-11-14 Kicad Schottkydiode added
    [VCO_RPIpico-B_Cu.gbr, VCO_RPIpico-B_Mask.gbr, VCO_RPIpico-B_Paste.gbr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]
2024-11-14 Kicad kleine Änderung
    [VCO_RPIpico-B_Cu.gbr, VCO_RPIpico-B_Mask.gbr, VCO_RPIpico-B_Paste.gbr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]
2024-11-14 Kicad Bezeichner hinzugefügt
    [VCO_RPIpico-B_Cu.gbr, VCO_RPIpico-B_Mask.gbr, VCO_RPIpico-B_Paste.gbr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]
2024-11-14 KiCad Nullserie finished
    [VCO_RPIpico-B_Cu.gbr, VCO_RPIpico-B_Mask.gbr, VCO_RPIpico-B_Paste.gbr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]
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2024-11-24 Bugfix: nach einschalten wurden bei FB1 die Parameter statt aus gespeicherten Daten von den Potis genommen
    [dubsiren_RP2040.ino]
2024-11-24 Values im Board wieder eingeblendet
    [VCO_RPIpico.kicad_pcb]
2024-11-25 PCB values enabled
    [VCO_RPIpico.kicad_pcb]
2024-11-27 3D Print STL Files added
    [Abstandshalter_LED.stl, Knob Fire - Inlay.stl, Knob Fire.stl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]
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2024-12-02 Gehäuseänderung
    [Body - Dubsiren_V10.stl, Knob Fire square.stl, Unterschale - Dubsiren_V10.stl]
2024-12-02 STL FIles
    [DIYStreifen.stl, Knob Fire - Inlay square.stl]
2024-12-08 Frontplatte DXF
    [DIYBody - Frontplatte.dxf]
2024-12-09 STL Files added
    [DIYDeckel_V10.1.stl, DIYDeckel_V11.1.stl, DIYKnob Fire - Inlay square.stl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]
2024-12-09 per Inkscape Frontplatte erstellt
    [DIYKnobFireInlaysquare_V11.0.stl, DIYKnobFireInlaysquare_V11.1.stl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]
2024-12-12 CAD: DXF Frontplatte, STL FIles
    [DIYBody - Frontplatte_EMS.dxf, DIYDeckel_V11.1_10mm.stl, DIYDeckel_V11.4_15mm.stl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]
2024-12-12 CAD: DXF Frontplatte korrigiert
    [DIYBody - Frontplatte_EMS.dxf]
2024-12-13 CAD new STL Files
    [DIYBody - Rahmen.stl, KNURL.stl, Knob_-_26mm.skp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]
2024-12-14 CAD: Frontplatte CAD/CAM
    [DIYBody - Frontplatte_EMS_1.dxf, DIYBody - Frontplatte_EMS_grosse_schrift.dxf]
2024-12-14 CAD: Potiknop angepasst, C: Letzter Firebutton bei Longpress korrigiert
    [dubsiren_RP2040.ino]
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2024-12-29 CAD: neuer Slim-Deckel
    [DIYBodyBottomSlim_V12.1.stl]
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2025-01-06 CAD: Shiftknopf 8mm
    [DIYKnobShift_V12.1.stl, PotiKnob_V12.0.stl, PotiKnob__10Inlay_V12.0.stl]
2025-01-06 File renamed
    [DIYKnobShift_V12.2_8mm.stl]
2025-01-07 CAD und eCAD
    [DIYKnobShift_V12.2_8mm.stl, VCO_RPIpico.kicad_sch]
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2025-01-31 CAD neue STL Version Gehäuse
    [DIYBodyBottomSlim_V12.3.stl, DIYKnobFire - Inlay_V12.3.stl, DIYKnobFire - Stößel_V12.3.stl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]
2025-03-03 CAD: STL Files added
    [CR10_DIYKnob_V12.3.3mf, DIYBodyStreifen.stl, DIYKnobFire - Stößel_V12.3_1.stl]
2025-03-06 CAD Potiknob STL
    [PotiKnobV25.stl, PotiKnob_V12.4.stl]
2025-03-06 CAD STP deleted
    [PotiKnob__10Inlay_V12.0.stl]
2025-03-13 KiCad: Supplier added for some parts
    [VCO_RPIpico.kicad_sch]
2025-03-18 KiCad: Schaltplan angepasst
    [VCO_RPIpico.kicad_pcb, VCO_RPIpico.kicad_sch]
2025-03-22 KiCad BOM erstellt
    [BOM\VCO_RPIpico.csv, VCO_RPIpico.csv, VCO_RPIpico.kicad_sch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]
2025-03-30 KiCad änderungen
    [VCO_RPIpico.kicad_pcb, VCO_RPIpico.kicad_sch]
2025-03-30 defekte datei gelöscht
    [BOM\VCO_RPIpico.csv]
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2025-06-04 drawings added
    [Frontplatte_EMS_grosse_schriftt_engrave_logo_lasergrbl.dxf]
2025-06-18 BOM reworked
    [DUB-IY-04_BOM.xlsx, VCO_RPIpico_BOM.ods]
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2025-06-19 BOM moved
    [DUB-IY-04_BOM.xlsx, VCO_RPIpico_BOM.ods]
2025-06-19 BOM ods
    [DUB-IY-04_BOM.ods, VCO_RPIpico_BOM.ods]
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2025-07-18 graphic frame border fix
2025-07-20 avoid noisy click with changing the mode of SoundPin to input when no tone is play
    [dubsiren_RP2040.ino]
2025-11-28 PCB correctur
    [VCO_RPIpico.kicad_pcb, VCO_RPIpico.kicad_sch]
2026-03-30 korrektur 260330
    [VCO_RPIpico.kicad_pcb]
2026-04-09 PCB rework
2026-08-24 Kicad: Muting control added
    [VCO_RPIpico.kicad_pcb, VCO_RPIpico.kicad_sch]
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2026-10-03 Oled-Display refres only when poti val changes fix1
    [dubsiren_RP2040.ino]
2026-10-04 Oled display integrated (#7)
    * Waveform preview combined LFO1+LFO2
    * Oled-Display refres only when poti val changes
    * Oled-Display refres only when poti val changes fix1
    * cleanup
    * Display-Refresh per Dirty-Flag, Wellenformvorschau
    [dubsiren_RP2040.ino]
2026-10-07 PWM Ramp at begin of tone to avoid noise, Sync LFO2 to LFO1 with Optionsflag2 ins. Cyclecount
    [dubsiren_RP2040.ino]
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
